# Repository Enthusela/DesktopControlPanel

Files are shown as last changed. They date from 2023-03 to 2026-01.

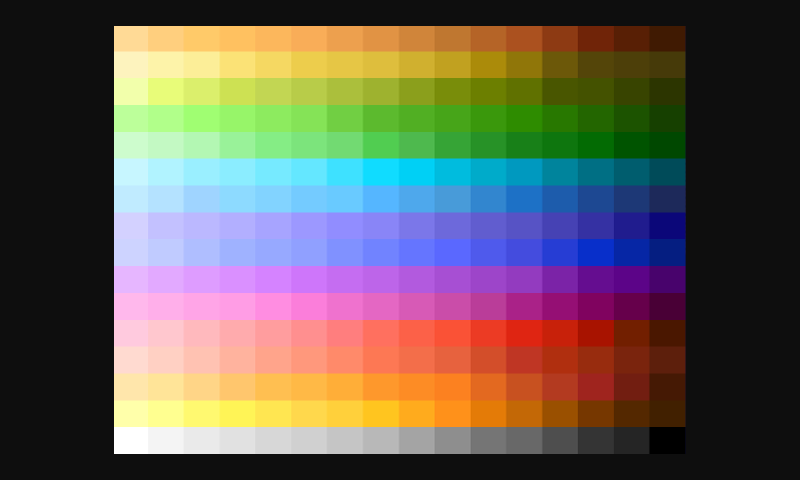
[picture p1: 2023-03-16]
eink/png/test256colors_resized.png

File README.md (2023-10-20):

# The Desktop Control Panel Project

20230719_201732_moneyShot

An open-source, hand-built, tactile, home-brew smart-home hub with analog PC audio monitoring and control.

## Features

* ARGB LED device control with HSV and color-temperature control modes
* App-based volume mixing in Windows, including OS/Game/Discord channels
* Motorised knobs enable multiple control modes on a single set of inputs
* Mains power control: Toggle switches control mains power to the PC, monitors, and speakers via rental-safe RF-based remote-control mains outlets.
* Analog audio monitoring: PC soundcard connects to VU meters and IN-9 Nixie Tubes for level and 3-band spectrum monitoring, respectively
* Moog-inspired build quality: wood cabinet, black brushed-aluminium faceplate, big, satisfying switchgear, and actual Moog knobs/rockers because why not.
* "Seamless" E-ink display: White-on-black E-ink panel creates a non-light-emitting display integrated into the non-light-emitting faceplate.
* Integrated website: the website for this Control Panel project is hosted on the Raspberry Pi running inside the Control Panel
* Integration with Home Assistant for ARGB room-lighting via ESP Wifi boards
* Automatic Temperature-based color control: automatically transition room lighting from cool to warm as the sun sets here in Perth, Western Australia.
* Homebrew phone-control app: Home Assistant has this, of course, but this sounded like a good excuse to learn React Native.

<details>
<summary>Feature Development Status Table</summary>

| Feature/Pipeline | Order In Pipeline | Sub-function | Status |
|:---|:---:|:---|:-----|
| Faceplate -> Mega Hardware Pipeline | 1 | Faceplate Input Hardware | Done |
| Faceplate -> Mega Hardware Pipeline | 2 | Faceplate Input Breakout Board | Testing |
| Faceplate -> Mega Hardware Pipeline | 3 | Mega* Input Shield | Testing |
| Mega -> Raspi Hardware Pipeline | 1 | USB Connection | Done |
| Raspi -> Uno Hardware Pipeline | 1 | USB Connection | Done |
| Raspi -> PC Hardware Pipeline | 1 | Local Wifi Connection | Done |
| Input Knob Motorisation | 1 | Mega Programming - Input Knob Control Modes | Done |
| Input Knob Motorisation | 2 | Motor Driver Shield | Done |
| Input Knob Motorisation | 3 | Shield -> Motor Connection | Done | 
| PC ARGB Control | 1 | Mega Programming - Input signal processing | Done |
| PC ARGB Control | 2a  | Raspi* Programming - Input passthrough to Uno | Done |
| PC ARGB Control | 2b  | Raspi Programming - Home Assistant/Web App | Not Started |
| PC ARGB Control | 3a  | Uno* Programming - Manual HSV-based Color Control | Done |
| PC ARGB Control | 3b  | Uno Programming - Manual Temp-based Color Control | Done |
| PC ARGB Control | 3c  | Uno Programming - Auto Temp-based Color Control | Not Started |
| PC ARGB Control | 4 | Uno ARGB Breakout Shield | To Be Ordered |
| PC ARGB Control | 5 | PC ARGB Devices | Done |
| PC Volume Control | 1 | Raspi Programming - Input passthrough to PC | Done |
| PC Volume Control | 2a  | PC Programming - Main Volume Control | Done |
| PC Volume Control | 2b  | PC Programming - Three-channel App Volume Control | Done |
| PC Volume Control | 2c  | PC Programming - Audio Output Device Selection | Done |
| Mains Power Control | 1 | Mega Programming - Input Signal Processing | In progress |
| Mains Power Control | 2 | Mega -> RF PCB Breakout Board | In progress |
| Mains Power Control | 3 | RF PCB -> Remote Mains Outlet Connection | In progress |
| Mains Power Control | 4 | Remote Mains Outlets - Test Working | In progress |
| PC Audio Level Meters | 1 | Soundcard TRS Output Levels | Done |
| PC Audio Level Meters | 2a  | Soundcard -> Driver Board Connection | Done |
| PC Audio Level Meters | 2b  | Power Supply -> Driver Board Connection | Developing |
| PC Audio Level Meters | 3 | VU Meter Driver Board | Done |
| PC Audio Level Meters | 4a  | VU Meter Level Outputs | Done |
| PC Audio Level Meters | 4b  | VU Meter LED Outputs | Done |
| PC Audio Level Meters | 5a  | VU Meters | Done |
| PC Audio Level Meters | 5b  | VU Meter LEDs | Prototyped |
| PC Audio Spectrum Analyser | 1 | Soundcard Optical Output Levels | Done |
| PC Audio Spectrum Analyser | 2 | Soundcard -> Digital I/O Board Connection | Done |
| PC Audio Spectrum Analyser | 3 | Raspberry Pi Digital Audio I/O Board | Testing |
| PC Audio Spectrum Analyser | 4 | Raspberry Pi Digital Audio I/O Processing | Developing |
| PC Audio Spectrum Analyser | 5 | Custom Nixie Tube Driver HAT | Developing |
| PC Audio Spectrum Analyser | 6 | Driver HAT -> Nixie Tube Connection | Done |
| PC Audio Spectrum Analyser | 7 | Power Supply to Driver Board | Developing |
| e-Ink Display | 1 | Raspberry Pi Programming - Image Output | Developing |
| e-Ink Display | 2 | Raspberry Pi HAT | Done |
| e-Ink Display | 3 | e-Ink Display | Done |
| Project Website | 1 | Proxy Server (nginx) | Done |
| Project Website | 2 | Domain Hosting | Done |
| Project Website | 3 | Server (node.js) | Done |
| Project Website | 4a  | Homepage | In progress |
| Project Website | 4b  | Brief | In progress |
| Project Website | 4c  | Timeline | In progress |
| Project Website | 4d  | Parts List | In progress |
| Project Website | 4e  | Gallery | In progress |
| Project Website | 4f  | Interactive Panel Map | Not started |
| Cabinet | N/A | Faceplate VU Meter Mounts | Done |
| Cabinet | N/A | Faceplate Nixie Tube Mounts | Done |
| Cabinet | N/A | Faceplate Soundcard Mount | Done |
| Cabinet | N/A | Faceplate e-Ink Display Mount | Done |
| Cabinet | N/A | Faceplate Input Knobs | Done |
| Cabinet | N/A | Faceplate Input Knob Motors/Gears | Done |
| Cabinet | N/A | Faceplate Input Rocker Switches | Done |
| Cabinet | N/A | Faceplate Input Toggle Switches | Done |
| Cabinet | N/A | Faceplate Input Push-button Switches | Done |
| Cabinet | N/A | Internal Mounting Plate | Done |
| Cabinet | N/A | Rear Plate Plate | Done |
| Cabinet | N/A | Cabinet Top Plate | Done |
| Cabinet | N/A | Cabinet Side Plates | Done |
| Cabinet | N/A | Cabinet Bottom Plate | In progress |
| Room ARGB Control | 1a  | Raspi Programming - Home Assistant Server | Not started |
| Room ARGB Control | 1b  | Raspi Programming - Home Assistant Phone App | Not started |
| Room ARGB Control | 2 | ESP32 Programming - Home Assistant Client | Not started |
| Room ARGB Control | 3 | ESP32 ARGB Breakout Shield | Prototyped  |
| Room ARGB Control | 4 | Room ARGB Devices - Confirm Working | Not started |
| e-Ink Touch Overlay | 1 | Touch Overlay | Not started |
| e-Ink Touch Overlay | 2 | Touch Overlay -> Raspi Connection | Not started |

* "Mega", "Raspi", and "Uno" refer to the Arduino Mega, Raspberry Pi, and Arduino Uno boards used, respectively.

</details>

## Background

This project grew out of a number of frustrations I was having building a killer PC setup that was both functional and aesthetically-pleasing: both important in a 1-by-1 apartment where said PC setup takes up a good third of the available living-room space.

<details>
<summary>ARGB controller software is not pleasant to use</summary>
<br>
The main idea for this project came out of my own frustration with existing hardware/software for controlling ARGB LEDs built into PC components. Most ARGB devices, like fans, must be plugged into a controller that interfaces with software running on the PC. This software is manufacturer-specific, closed-source, and typically quite limited in what it can do: you get some pre-loaded color patterns, but if you want it to do anything else, you're out of luck. To make matters worse, the software is often classic "bloatware": it insists on starting on login, then runs slow, chews up computer resources on functions you didn't ask for, and crashes often. Factor in multiple apps running for different manufacturers, and the user experience gets frustrating fast. While there is some scope to synchronise lighting across different manufacturer's products, these aren't ideal either: I was able to sync my CoolerMaster fans and my Corsair mouse, for instance, but only by using ARGB software tied to my motherboard, which was more limited than the software that came with either product.
</details> 

<details>
<summary>ARGB controller hardware is not special</summary>
<br>
Despite these software problems, I noticed that the physical connections across all my devices was using the same three-pin standard. A quick internet search taught me that the standard was, as expected, a simple Vcc-Data-Gnd pin layout.
</details>

<details>
<summary>Humans did not evolve to relax under rainbow lighting</summary>
<br>
While thinking about making my own ARGB controller, one feature that I particularly wanted was temperature-based color control. I liked the idea of room lighting that could change from cool white during the day to very warm, basically orange, at night. Ideally I'd have my whole apartment lit up like this to make it a well-lit space during the day that gradually becomes softer, warmer, and hopefully more sleep-conducive at night. This is pretty much the antithesis of most pre-built ARGB options, whether that's PC components or ARGB strip-lighting with controllers, which default to "rainbow vomit cyclone". Of course, if I had my own controller then I could make my color-temperature dreams come true.
</details>

<details>
<summary>I like my hardware ~ t e x t u r a l ~</summary>
<br>
I don't know about you, but I really love old-school electronics hardware, particularly audio hardware like synthesisers, amps, mixing tables, etc. The use of materials like wood and metal and glass makes them look and feel so much nicer, so much more hand-crafted, than anything you can get out of molded plastic. All that physical switchgear gives it a sense of weight and purpose; you just know there's a heap of clever analog wizardry going on in there as you move physical components about. It's kind of the opposite of the experience I was getting with the ARGB controllers, which is basically "plug in this small plastic box and hope the software will work". If I was ever going to build my own electronics hardware, something really cool, it would take a lot of design queues from that kind of old-school equipment.
</details>

<details>
<summary>I wanted a new job</summary>
<br>
This project became part of my Master Plan to pivot from Mechatronics Engineer to Software Engineer. If everything so far sounds like something I could have just bought one or more smart-home products to do, then yes, you're right, but as the feature set grew I realised varied tech stack required to build it would make it an ideal showcase project.
</details>

<details>
<summary>The Idea</summary>
<br>
So I have lighting software that doesn't work, connected to hardware that isn't complicated, pushing out colors I don't like, in a form factor that's the opposite of what I like in technology. What if I made the opposite of that? An open-source controller, accepting whatever standard plug-ins my devices used, with all of the color-control options I could think up, built into a sleek bit of hardware that makes you go "Nice." Maybe it'd look a little like this...
<br>
20220818_153445_ControlPanelDiagram

This repo contains (almost) everything I've built so far to make bring that digital finger-painting to life.
</details>

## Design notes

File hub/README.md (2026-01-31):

# Desktop Control Hub

Central coordination web application for the Desktop Control Panel system. This hub manages communication between various devices (Arduino, ESP32, Raspberry Pi) and provides a unified web interface for control and monitoring.

## Architecture

```
Browser (Web UI)
    ↕ Socket.IO
Hub (Node.js Server)
    ↕ Serial/GPIO/Network
Devices (Arduino, ESP32, etc.)
```

## Features

- **Real-time Communication**: Socket.IO for bidirectional updates
- **Device Coordination**: Manages multiple external devices
- **ARGB Control**: Controls addressable RGB LEDs via Arduino
- **GPIO Support**: Raspberry Pi GPIO integration (with mock mode for development)
- **Containerized**: Docker support for easy deployment

## Quick Start

### Development (Local Machine)

```bash
cd hub

# Start with Docker Compose
docker-compose up

# Or run directly with Node.js
npm install
node webserver.js
```

Access the web interface at: http://localhost:8080

### Production (Raspberry Pi)

```bash
cd hub

# Copy and configure environment
cp .env.example .env
# Edit .env with your settings

# Start production container
docker-compose -f docker-compose.prod.yml up -d
```

## Configuration

Environment variables (`.env`):

- `SERIAL_PORT`: Arduino serial port (default: `/dev/ttyACM0`)
- `GPIO_MODE`: `hardware` for Raspberry Pi, `mock` for development (default: `mock`)
- `NODE_ENV`: `development` or `production` (default: `development`)

## Device Integration

### Arduino (ARGB Control)

- **Protocol**: Serial @ 9600 baud
- **Format**: `_` + HSV bytes (Hue, Saturation, Value)
- **Device**: `/dev/ttyACM0`

### Raspberry Pi GPIO

- **LED**: GPIO 21 (output)
- **Button**: GPIO 26 (input)

## Development

### File Structure

```
hub/
├── public/              # Static web files
│   ├── index.html      # Web UI
│   └── index.js        # Client-side JavaScript
├── webserver.js        # Node.js server
├── package.json        # Dependencies
├── Dockerfile          # Container definition
└── docker-compose.yml  # Development orchestration
```

### Running without Docker

```bash
npm install
node webserver.js
```

### Hot Reload

The development Docker container uses nodemon for automatic restarts when code changes.

## API Events (Socket.IO)

### Client → Server

- `onOff` - Toggle power (0/1)
- `hsv_hue` - Set hue (0-255)
- `hsv_saturation` - Set saturation (0-255)
- `hsv_brightness` - Set brightness (0-255)

### Server → Client

- `onOff` - Power state update
- `connect` - Connection established
- `disconnect` - Connection lost

## Troubleshooting

### Arduino not detected

```bash
# List available serial ports
arduino-cli board list

# Update SERIAL_PORT in .env
```

### Permission denied on serial port

```bash
# Add user to dialout group
sudo usermod -a -G dialout $USER
# Log out and back in
```

### GPIO not working

- Ensure `GPIO_MODE=hardware` on Raspberry Pi
- Check GPIO pins are not in use by other processes
- Verify user has GPIO permissions

## Related Components

- **argb_ctrl/ard_uno/**: Arduino firmware for ARGB control
- **argb_ctrl/raspi/**: Raspberry Pi integration scripts
- **argb_ctrl/esp_wifi/**: ESP32 WiFi controller

## Future Plans

- Multi-device dashboard
- E-ink display integration
- Cabinet lighting control
- Temperature monitoring
- System status display

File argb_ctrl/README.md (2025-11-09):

# ARGB Controller - Containerized Setup

A containerized RGB LED controller that runs on both development machines and Raspberry Pi, communicating with Arduino via USB serial.

## Architecture

- **Web Interface**: Node.js server with Socket.IO for real-time control
- **Arduino Communication**: Serial connection via USB (default: `/dev/ttyACM0`)
- **GPIO Control**: Physical button support on Raspberry Pi (gracefully disabled on other systems)
- **Container**: Docker-based deployment for portability

## Prerequisites

### Development Machine
- Docker and Docker Compose installed
- Arduino connected via USB
- Linux host (for USB device passthrough)

### Raspberry Pi
- Docker and Docker Compose installed
- Arduino connected via USB
- GPIO pins 21 (LED) and 26 (button) wired (optional)

## Quick Start

### Development Mode (Your Local Machine)

1. **Find your Arduino device path:**
   ```bash
   ls -l /dev/ttyACM* /dev/ttyUSB*
   ```

2. **Update device path if needed:**
   Edit `docker-compose.yml` and update the device path:
   ```yaml
   devices:
     - /dev/ttyACM0:/dev/ttyACM0  # Change if your Arduino is on a different port
   ```

3. **Start the container:**
   ```bash
   cd argb_ctrl
   docker compose up --build
   ```

4. **Access the web interface:**
   Open your browser to `http://localhost:8080`

### Production Mode (Raspberry Pi)

1. **Build and start:**
   ```bash
   cd argb_ctrl
   docker compose -f docker-compose.prod.yml up --build -d
   ```

2. **Access the web interface:**
   From any device on the network: `http://<raspberry-pi-ip>:8080`

## Configuration

### Environment Variables

You can customize behavior in two ways:

**Option 1: Using a .env file (recommended)**
```bash
# Copy the example file and edit it
cp .env.example .env
# Edit .env with your preferred settings
```

**Option 2: Direct environment variables**
```bash
# Set before running docker compose
export SERIAL_PORT=/dev/ttyUSB0
export GPIO_MODE=mock
docker compose up
```

Available variables:
- `GPIO_MODE`: 'mock' (disable GPIO) or 'hardware' (enable GPIO)
- `SERIAL_PORT`: Arduino serial port path (default: /dev/ttyACM0)
- `NODE_ENV`: 'development' or 'production'

### USB Device Permissions

If you encounter permission errors accessing the Arduino:

```bash
# Add your user to the dialout group
sudo usermod -aG dialout $USER

# Or set device permissions (temporary, resets on reboot)
sudo chmod 666 /dev/ttyACM0
```

## Development Features

### Hot Reload
In development mode, the container uses `nodemon` to automatically restart when you edit:
- `webserver.js`
- `public/index.html`
- `public/index.js`

Changes are reflected immediately without rebuilding the container.

### Logs
```bash
# View logs
docker compose logs -f

# View only errors
docker compose logs -f | grep -i error
```

## Troubleshooting

### Arduino Not Found
```
Error: Error: Error Resource temporarily unavailable Cannot lock port
```
**Solution**:
- Check the device path: `ls -l /dev/ttyACM*`
- Update `docker-compose.yml` with correct device path
- Ensure the device isn't already open by another program
- Check permissions (see USB Device Permissions above)

### GPIO Errors on Non-Raspberry Pi
This is normal. The application will log:
```
GPIO not available: ...
Running in mock GPIO mode - physical button will not work
```
This is expected behavior on development machines. The web interface will still work.

### Port 8080 Already in Use
```bash
# Find and kill the process using port 8080
sudo lsof -i :8080
sudo kill -9 <PID>
```

### Container Won't Start
```bash
# Clean rebuild
docker compose down
docker compose up --build
```

## Project Structure

```
argb_ctrl/
├── docker-compose.yml          # Development configuration
├── docker-compose.prod.yml     # Production configuration (Raspberry Pi)
├── web_app/
│   ├── Dockerfile              # Container definition
│   ├── .dockerignore          # Files to exclude from container
│   ├── package.json           # Node.js dependencies
│   ├── webserver.js           # Main server application
│   └── public/
│       ├── index.html         # Web interface
│       └── index.js           # Client-side JavaScript
├── raspi/
│   └── ard.py                 # Python control script (alternative)
└── ard_uno/
    └── ARGBController.ino     # Arduino sketch
```

## Arduino Setup

1. Flash the Arduino with `ard_uno/ARGBController.ino`
2. Connect the Arduino via USB
3. The Arduino should appear as `/dev/ttyACM0` (or similar)
4. The web server will communicate using the protocol:
   - Send: `_` + 3 bytes (H, S, V values 0-255)
   - When off: `_` + 0, 0, 0

## Stopping the Application

### Development
```bash
docker compose down
```

### Production
```bash
docker compose -f docker-compose.prod.yml down
```

## Building for Different Platforms

### ARM64 (Raspberry Pi 4)
```bash
docker buildx build --platform linux/arm64 -t argb-web-app ./web_app
```

### AMD64 (Standard PC)
```bash
docker buildx build --platform linux/amd64 -t argb-web-app ./web_app
```

## Next Steps

1. Test the setup on your development machine
2. Customize the Arduino sketch for your RGB LED setup
3. Deploy to Raspberry Pi when ready
4. Configure autostart on Raspberry Pi boot (optional):
   ```bash
   # Add to /etc/rc.local (before 'exit 0')
   cd /path/to/argb_ctrl && docker compose -f docker-compose.prod.yml up -d
   ```

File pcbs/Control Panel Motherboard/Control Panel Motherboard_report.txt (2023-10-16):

PCB statistics report
=====================
- Date: 19/09/2023 2:00:27 PM
- Project: Control Panel Motherboard
- Board name: Control Panel Motherboard

Board
-----
- Width: 91.3384 mm
- Height: 74.6760 mm
- Area: 6820.7864 mm²

Pads
----
- Through hole: 159
- SMD: 0
- Connector: 0
- NPTH: 0

Vias
----
- Through vias: 0
- Blind/buried: 0
- Micro vias: 0

Components
----------

| | Front Side | Back Side | Total |
|---|---|---|---|
|THT: | 43 | 0 | 43 |
|SMD: | 0 | 0 | 0 |
|Unspecified:  | 0 | 0 | 0 |
|Total: | 43 | 0 | 43 |

Drill holes
-----------

| Count | Shape | X Size | Y Size | Plated | Via/Pad | Start Layer | Stop Layer |
|---|---|---|---|---|---|---|---|
| 59 | Round | 1.5200 mm | 1.5200 mm | PTH | Pad | F.Cu | B.Cu |
| 36 | Round | 0.8000 mm | 0.8000 mm | PTH | Pad | F.Cu | B.Cu |
| 30 | Round | 1.0000 mm | 1.0000 mm | PTH | Pad | F.Cu | B.Cu |
| 18 | Round | 0.7000 mm | 0.7000 mm | PTH | Pad | F.Cu | B.Cu |
| 16 | Round | 0.9000 mm | 0.9000 mm | PTH | Pad | F.Cu | B.Cu |

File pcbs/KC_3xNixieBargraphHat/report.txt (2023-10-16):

Info: Backing up file 'C:\Users\natha\OneDrive\Documents\Projects\Control Panel\Custom PCBs\KC_3xNixieBargraphHat\sym-lib-table' to 'C:\Users\natha\OneDrive\Documents\Projects\Control Panel\Custom PCBs\KC_3xNixieBargraphHat\rescue-backup\sym-lib-table-2023-09-20-15-47-16'.
Info: Backing up file 'C:\Users\natha\OneDrive\Documents\Projects\Control Panel\Custom PCBs\KC_3xNixieBargraphHat\KC_3xNixieBargraphHat.sch' to 'C:\Users\natha\OneDrive\Documents\Projects\Control Panel\Custom PCBs\KC_3xNixieBargraphHat\rescue-backup\KC_3xNixieBargraphHat-2023-09-20-15-47-16.sch'.
Info: Backing up file 'C:\Users\natha\OneDrive\Documents\Projects\Control Panel\Custom PCBs\KC_3xNixieBargraphHat\KC_3xNixieBargraphHat.kicad_pro' to 'C:\Users\natha\OneDrive\Documents\Projects\Control Panel\Custom PCBs\KC_3xNixieBargraphHat\rescue-backup\KC_3xNixieBargraphHat-2023-09-20-15-47-16.kicad_pro'.
Info: Backing up file 'C:\Users\natha\OneDrive\Documents\Projects\Control Panel\Custom PCBs\KC_3xNixieBargraphHat\KC_3xNixieBargraphHat-cache.lib' to 'C:\Users\natha\OneDrive\Documents\Projects\Control Panel\Custom PCBs\KC_3xNixieBargraphHat\rescue-backup\KC_3xNixieBargraphHat-cache-2023-09-20-15-47-16.lib'.
Info: Backing up file 'C:\Users\natha\OneDrive\Documents\Projects\Control Panel\Custom PCBs\KC_3xNixieBargraphHat\KC_3xNixieBargraphHat-rescue.lib' to 'C:\Users\natha\OneDrive\Documents\Projects\Control Panel\Custom PCBs\KC_3xNixieBargraphHat\rescue-backup\KC_3xNixieBargraphHat-rescue-2023-09-20-15-47-16.lib'.
Info: Backing up file 'C:\Users\natha\OneDrive\Documents\Projects\Control Panel\Custom PCBs\KC_3xNixieBargraphHat\KC_3xNixieBargraphHat-rescue.dcm' to 'C:\Users\natha\OneDrive\Documents\Projects\Control Panel\Custom PCBs\KC_3xNixieBargraphHat\rescue-backup\KC_3xNixieBargraphHat-rescue-2023-09-20-15-47-16.dcm'.
Info: Adding library 'KC_3xNixieBargraphHat-rescue', file '${KIPRJMOD}/KC_3xNixieBargraphHat-rescue.lib' to project symbol library table.
Symbol R mapped to symbol library 'KC_3xNixieBargraphHat-rescue'.
Symbol GND mapped to symbol library 'KC_3xNixieBargraphHat-rescue'.
Symbol +170V mapped to symbol library 'KC_3xNixieBargraphHat-rescue'.
Symbol Screw_Terminal_1x02 mapped to symbol library 'KC_3xNixieBargraphHat-rescue'.
Symbol GND mapped to symbol library 'KC_3xNixieBargraphHat-rescue'.
Symbol Screw_Terminal_1x03 mapped to symbol library 'KC_3xNixieBargraphHat-rescue'.
Symbol R mapped to symbol library 'KC_3xNixieBargraphHat-rescue'.
Symbol +170V mapped to symbol library 'KC_3xNixieBargraphHat-rescue'.
Symbol Screw_Terminal_1x03 mapped to symbol library 'KC_3xNixieBargraphHat-rescue'.
Symbol +5V mapped to symbol library 'KC_3xNixieBargraphHat-rescue'.
Symbol IN-9 mapped to symbol library 'KC_3xNixieBargraphHat-rescue'.
Symbol +170V mapped to symbol library 'KC_3xNixieBargraphHat-rescue'.
Symbol BSP129 mapped to symbol library 'KC_3xNixieBargraphHat-rescue'.
Symbol Screw_Terminal_1x03 mapped to symbol library 'KC_3xNixieBargraphHat-rescue'.
Symbol R mapped to symbol library 'KC_3xNixieBargraphHat-rescue'.
Symbol GND mapped to symbol library 'KC_3xNixieBargraphHat-rescue'.
Symbol R mapped to symbol library 'KC_3xNixieBargraphHat-rescue'.
Symbol GND mapped to symbol library 'KC_3xNixieBargraphHat-rescue'.
Symbol R mapped to symbol library 'KC_3xNixieBargraphHat-rescue'.
Symbol +3.3V mapped to symbol library 'KC_3xNixieBargraphHat-rescue'.
Symbol GND mapped to symbol library 'KC_3xNixieBargraphHat-rescue'.
Symbol Raspberry_PI_Zero_Hat mapped to symbol library 'KC_3xNixieBargraphHat-rescue'.
Symbol R mapped to symbol library 'KC_3xNixieBargraphHat-rescue'.
Symbol GND mapped to symbol library 'KC_3xNixieBargraphHat-rescue'.
Symbol GND mapped to symbol library 'KC_3xNixieBargraphHat-rescue'.
Symbol R mapped to symbol library 'KC_3xNixieBargraphHat-rescue'.
Symbol R mapped to symbol library 'KC_3xNixieBargraphHat-rescue'.
Symbol R mapped to symbol library 'KC_3xNixieBargraphHat-rescue'.
Symbol R mapped to symbol library 'KC_3xNixieBargraphHat-rescue'.
Symbol +5V mapped to symbol library 'KC_3xNixieBargraphHat-rescue'.
Symbol R mapped to symbol library 'KC_3xNixieBargraphHat-rescue'.
Symbol R mapped to symbol library 'KC_3xNixieBargraphHat-rescue'.
Symbol R mapped to symbol library 'KC_3xNixieBargraphHat-rescue'.
Symbol R mapped to symbol library 'KC_3xNixieBargraphHat-rescue'.
Symbol R mapped to symbol library 'KC_3xNixieBargraphHat-rescue'.
Symbol BSP129 mapped to symbol library 'KC_3xNixieBargraphHat-rescue'.
Symbol IN-9 mapped to symbol library 'KC_3xNixieBargraphHat-rescue'.
Symbol MCP6001 mapped to symbol library 'KC_3xNixieBargraphHat-rescue'.
Symbol C mapped to symbol library 'KC_3xNixieBargraphHat-rescue'.
Symbol 2N7002 mapped to symbol library 'KC_3xNixieBargraphHat-rescue'.
Symbol GND mapped to symbol library 'KC_3xNixieBargraphHat-rescue'.
Symbol R mapped to symbol library 'KC_3xNixieBargraphHat-rescue'.
Symbol R mapped to symbol library 'KC_3xNixieBargraphHat-rescue'.
Symbol R mapped to symbol library 'KC_3xNixieBargraphHat-rescue'.
Symbol C mapped to symbol library 'KC_3xNixieBargraphHat-rescue'.
Symbol GND mapped to symbol library 'KC_3xNixieBargraphHat-rescue'.
Symbol C mapped to symbol library 'KC_3xNixieBargraphHat-rescue'.
Symbol GND mapped to symbol library 'KC_3xNixieBargraphHat-rescue'.
Symbol C mapped to symbol library 'KC_3xNixieBargraphHat-rescue'.
Symbol GND mapped to symbol library 'KC_3xNixieBargraphHat-rescue'.
Symbol GND mapped to symbol library 'KC_3xNixieBargraphHat-rescue'.
Symbol GND mapped to symbol library 'KC_3xNixieBargraphHat-rescue'.
Symbol R mapped to symbol library 'KC_3xNixieBargraphHat-rescue'.
Symbol GND mapped to symbol library 'KC_3xNixieBargraphHat-rescue'.
Symbol D_x2_Serial_AKC mapped to symbol library 'KC_3xNixieBargraphHat-rescue'.
Symbol D_x2_Serial_AKC mapped to symbol library 'KC_3xNixieBargraphHat-rescue'.
Symbol +3.3V mapped to symbol library 'KC_3xNixieBargraphHat-rescue'.
Symbol C mapped to symbol library 'KC_3xNixieBargraphHat-rescue'.
Symbol +5V mapped to symbol library 'KC_3xNixieBargraphHat-rescue'.
Symbol +3.3V mapped to symbol library 'KC_3xNixieBargraphHat-rescue'.
Symbol R mapped to symbol library 'KC_3xNixieBargraphHat-rescue'.
Symbol D_x2_Serial_AKC mapped to symbol library 'KC_3xNixieBargraphHat-rescue'.
Symbol C mapped to symbol library 'KC_3xNixieBargraphHat-rescue'.
Symbol GND mapped to symbol library 'KC_3xNixieBargraphHat-rescue'.
Symbol GND mapped to symbol library 'KC_3xNixieBargraphHat-rescue'.
Symbol GND mapped to symbol library 'KC_3xNixieBargraphHat-rescue'.
Symbol D_x2_Serial_AKC mapped to symbol library 'KC_3xNixieBargraphHat-rescue'.
Symbol R mapped to symbol library 'KC_3xNixieBargraphHat-rescue'.
Symbol R mapped to symbol library 'KC_3xNixieBargraphHat-rescue'.
Symbol 2N7002 mapped to symbol library 'KC_3xNixieBargraphHat-rescue'.
Symbol GND mapped to symbol library 'KC_3xNixieBargraphHat-rescue'.
Symbol C mapped to symbol library 'KC_3xNixieBargraphHat-rescue'.
Symbol R mapped to symbol library 'KC_3xNixieBargraphHat-rescue'.
Symbol R mapped to symbol library 'KC_3xNixieBargraphHat-rescue'.
Symbol GND mapped to symbol library 'KC_3xNixieBargraphHat-rescue'.
Symbol +5V mapped to symbol library 'KC_3xNixieBargraphHat-rescue'.
Symbol C mapped to symbol library 'KC_3xNixieBargraphHat-rescue'.
Symbol GND mapped to symbol library 'KC_3xNixieBargraphHat-rescue'.
Symbol MCP6001 mapped to symbol library 'KC_3xNixieBargraphHat-rescue'.
Symbol C mapped to symbol library 'KC_3xNixieBargraphHat-rescue'.
Symbol GND mapped to symbol library 'KC_3xNixieBargraphHat-rescue'.
Info: Symbol library table mapping complete!
Info: Created project symbol library table.

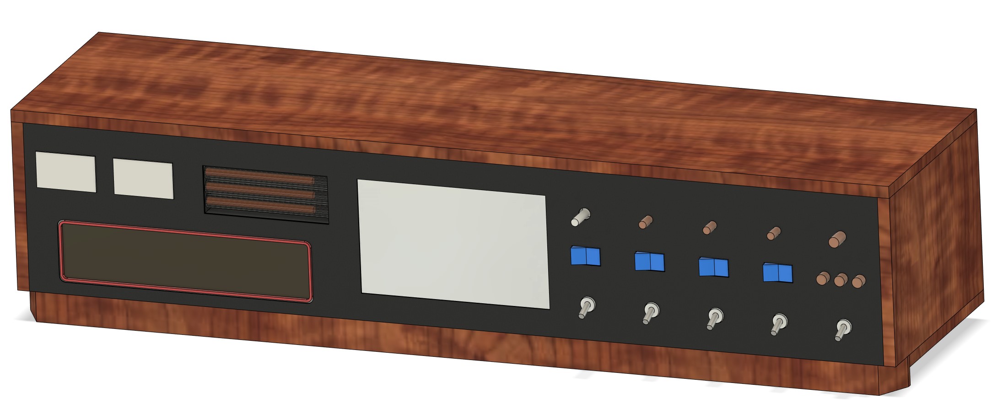
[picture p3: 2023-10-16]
cabinet/imgs/Control Panel Mock-up - Face Plate.jpg

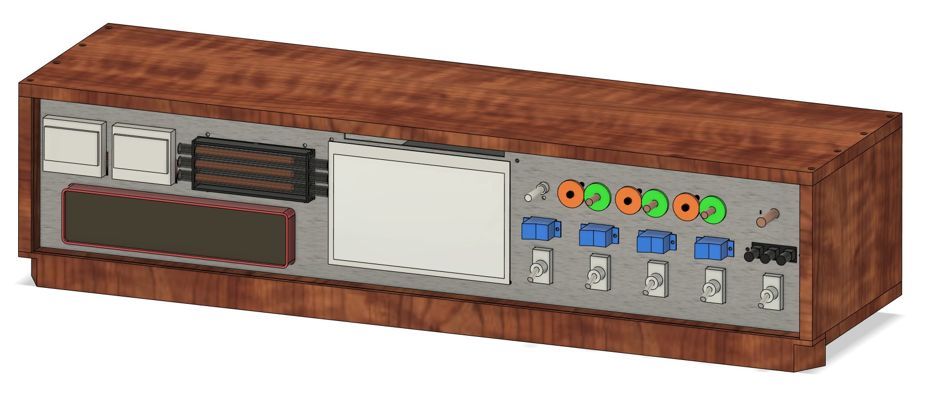
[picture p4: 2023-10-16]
cabinet/imgs/Control Panel Mock-up - Mounting Plate.jpg

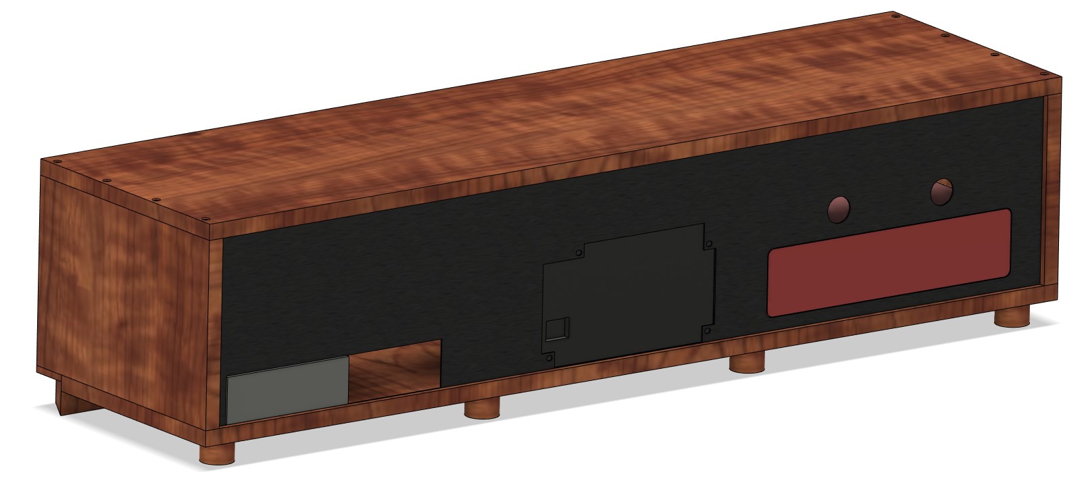
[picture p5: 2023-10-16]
cabinet/imgs/Control Panel Mock-up - Rear Plate.jpg

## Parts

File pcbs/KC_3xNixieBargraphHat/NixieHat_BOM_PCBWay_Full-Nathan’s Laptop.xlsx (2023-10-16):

 |  |  | xxxx xxxx xxxxx xxPCS BOM
 |  |  |  |  |  | 30
Item # | *Designator | *Qty | Manufacturer | *Mfg Part # | Description / Value | *Package/Footprint | Type | Your Instructions / Notes
1 | C1, C5, C10 | 3 | Kemet | C0805C332J4HACTU | 3.3nF | Capacitor_SMD:C_0805_2012Metric_Pad1.18x1.45mm_HandSolder | SMD | Found at: https://www.xonelec.com/mpn/kemet/c0805c332j4hactu
2 | C2, C6, C11 | 3 | Kemet | C0805C104J8RACTU | 0.1uF | Capacitor_SMD:C_0805_2012Metric_Pad1.18x1.45mm_HandSolder | SMD | Found at: https://www.xonelec.com/mpn/kemet/c0805c104j8ractu
3 | C3, C4, C7, C13 | 4 | Kemet | C0805C105J4RACTU | 1uF | Capacitor_SMD:C_0805_2012Metric_Pad1.18x1.45mm_HandSolder | SMD | Found at: https://www.xonelec.com/mpn/kemet/c0805c105j4ractu
4 | C8, C9, C12 | 3 | Kemet | C0805C102J4GACTU | 1nF | Capacitor_SMD:C_0805_2012Metric_Pad1.18x1.45mm_HandSolder | SMD | Found at: https://www.xonelec.com/mpn/kemet/c0805c102j4gactu
5 | D1-D6 | 6 | Nexperia USA Inc. | BAV99,215 | BAV99 | Package_TO_SOT_SMD:SOT-23 | SMD | Found at: https://www.pcbway.com/components/detail/BAV99215/340224/
6 | J1-J3 | 3 | Molex | 0397730002 | Screw_Terminal_1x02 | TerminalBlock_Phoenix:TerminalBlock_Phoenix_MPT-0,5-2-2.54_1x02_P2.54mm_Horizontal | PTH | Found at: https://www.pcbway.com/components/detail/0397730002/883047/
7 | Q1, Q3, Q5 | 3 | ON Semiconductor | FDD7N25LZTM | FDD7N25LZTM | Package_TO_SOT_SMD:TO-252-2 | SMD | Found at: https://www.xonelec.com/mpn/onsemiconductor/fdd7n25lztm
8 | Q2, Q4, Q6 | 3 | Micro Commercial Components (MCC) | 2N7002-TP | 2N7002 | Package_TO_SOT_SMD:SOT-23 | SMD | Found at: https://www.xonelec.com/mpn/microcommercialcomponentsmcc/2n7002tp
9 | R1, R2, R5-R10, R20, R25-R28 | 13 | Yageo | RT0805FRE071KL | 1k | Resistor_SMD:R_0805_2012Metric_Pad1.20x1.40mm_HandSolder | SMD
10 | R3, R11, R29 | 3 | Vishay | PR02000201001FR500 | 1k 2W | Resistor_THT:R_Axial_DIN0411_L9.9mm_D3.6mm_P12.70mm_Horizontal | PTH
11 | R4, R12, R22, R30 | 3 | Yageo | RT0805FRE07130RL | 133 | Resistor_SMD:R_0805_2012Metric_Pad1.15x1.40mm_HandSolder | SMD
12 | R18 | 1 | Yageo | RT0805FRE07100KL | 100k | Resistor_SMD:R_0805_2012Metric_Pad1.20x1.40mm_HandSolder | SMD
13 | R32 | 1 | Yageo | RT0805FRE0747KL | 47k | Resistor_SMD:R_0805_2012Metric_Pad1.20x1.40mm_HandSolder | SMD
14 | U1, U3, U4 | 3 | Microchip | MCP6411T-E/OT | MCP6411 | Package_TO_SOT_SMD:TSOT-23-5_HandSoldering | SMD | Found at: https://www.xonelec.com/mpn/microchip/mcp6411teot
15 | U5 | 1 | Lite-on | LTV-817-A | LTV-817 | Package_DIP:DIP-4_W7.62mm | PTH
Need a quick and accurante quote? Need an efficient production? Please read SMT Ordering Necessary Files & Info in 1 minute. Thank you very much! (https://www.pcbway.com/smt_ordering_guide.html)
Click for Instructions on How to Create a BOM (https://www.pcbway.com/blog/PCB_Assembly/How_to_Build_a_BOM__Bill_Of_Materials_.html)

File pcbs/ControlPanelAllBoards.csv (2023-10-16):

Board | Qty | In Mouser Cart | In Jaycar Cart | In X-On Cart | Footprint | Reference | Value | Datasheet
Selector | 13 | N/A | N/A | N/A | Connector_Pin:Pin_D1.0mm_L10.0mm | > J1-J13 | Conn_01x01_Female | ~
Mega_Shield | 1 | N/A | N/A | N/A | PCM_arduino-library:Arduino_Mega2560_Shield | XA1 | Arduino_Mega2560_Shield | https://docs.arduino.cc/hardware/mega-2560
MegaShield | 1 | No | Yes | No | Connector_IDC:IDC-Header_2x05_P2.54mm_Vertical | J3 | IDC_RF | ~
RF_Breakout | 1 | No | Yes | No | Connector_IDC:IDC-Header_2x05_P2.54mm_Vertical | IDC_RF1 | IDC_SW | ~
MegaShield | 1 | Yes | Yes | No | Connector_IDC:IDC-Header_2x10_P2.54mm_Vertical | J1 | IDC_SW | ~
IO_Breakout | 1 | No | Yes | No | Connector_IDC:IDC-Header_2x10_P2.54mm_Vertical | J11 | J_IDC_SW_IN | ~
MegaShield | 1 | No | Yes | No | IDC Cable _2x05 _P2.54mm_Vertical | N/A
MegaShield | 1 | No | Yes | No | IDC Cable _2x10 _P2.54mm_Vertical | N/A
MegaShield | 1 | Yes |  | Yes | Button_Switch_THT:SW_DIP_SPSTx02_Slide_9.78x7.26mm_W7.62mm_P2.54mm | SW2 | SW_DIP_x02 | ~
MegaShield | 1 | Yes |  | Yes | Button_Switch_THT:SW_PUSH_6mm_H5mm | SW1 | SW_Push | ~
RF_Breakout | 4 | Yes |  | Yes | LED_THT:LED_D3.0mm | > D1, D3, D5, D7 | LED-ON | ~
RF_Breakout | 4 | Yes |  | Yes | LED_THT:LED_D3.0mm | > D2, D4, D6, D8 | LED-OFF | ~
RF_Breakout | 2 | Yes |  | Yes | Package_DIP:DIP-16_W7.62mm | > U2, U3 | LTV-847 | http://optoelectronics.liteon.com/upload/download/DS-70-96-0016/LTV-8X7%20series.PDF
IO_Breakout | 1 | Yes |  | Yes | Package_DIP:DIP-4_W7.62mm | U1 | LTV-817 | http://www.us.liteon.com/downloads/LTV-817-827-847.PDF
Selector | 12 | No |  | Yes | Resistor_THT:R_Axial_DIN0204_L3.6mm_D1.6mm_P5.08mm_Horizontal | > R1-R12 | 330R | ~
IO_Breakout | 1 | Yes |  | Yes | Resistor_THT:R_Axial_DIN0207_L6.3mm_D2.5mm_P7.62mm_Horizontal | R1 | 330R | ~
RF_Breakout | 8 | No |  | Yes | Resistor_THT:R_Axial_DIN0207_L6.3mm_D2.5mm_P7.62mm_Horizontal | > R2-R9 | 330R | ~
IO_Breakout | 3 | Yes |  | Yes | TerminalBlock:TerminalBlock_bornier-2_P5.08mm | > J9, J10, J12 | Screw_Terminal_01x02 | ~
RF_Breakout | 1 | Yes |  | Yes | TerminalBlock:TerminalBlock_bornier-2_P5.08mm | J22 | Screw_Terminal_01x02 | ~
MegaShield | 1 | Yes |  | Yes | TerminalBlock:TerminalBlock_bornier-3_P5.08mm | J2 | Screw_Terminal_01x03 | ~
Selector | 1 | Yes |  | Yes | TerminalBlock:TerminalBlock_bornier-3_P5.08mm | J14 | Screw_Terminal_01x03 | ~
IO_Breakout | 13 | Yes |  | Yes | TerminalBlock:TerminalBlock_bornier-3_P5.08mm | > J1-J8, J13-J17 | Screw_Terminal_01x03 | ~
RF_Breakout | 4 | Yes |  | Yes | TerminalBlock:TerminalBlock_bornier-3_P5.08mm | > J18-J21 | Screw_Terminal_01x03 | ~

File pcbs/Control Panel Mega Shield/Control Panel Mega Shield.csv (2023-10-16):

Reference | Value | Footprint | Datasheet | Qty
J1 | IDC_SW | Connector_IDC:IDC-Header_2x10_P2.54mm_Vertical | ~ | 1
J2 | Screw_Terminal_01x03 | TerminalBlock:TerminalBlock_bornier-3_P5.08mm | ~ | 1
J3 | IDC_RF | Connector_IDC:IDC-Header_2x05_P2.54mm_Vertical | ~ | 1
SW1 | SW_Push | Button_Switch_THT:SW_PUSH_6mm_H5mm | ~ | 1
SW2 | SW_DIP_x02 | Button_Switch_THT:SW_DIP_SPSTx02_Slide_9.78x7.26mm_W7.62mm_P2.54mm | ~ | 1
XA1 | Arduino_Mega2560_Shield | PCM_arduino-library:Arduino_Mega2560_Shield | https://docs.arduino.cc/hardware/mega-2560 | 1

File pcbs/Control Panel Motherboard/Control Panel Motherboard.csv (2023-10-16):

Reference | Value | Footprint | Datasheet | Qty
D1-D8 | LED | LED_THT:LED_D3.0mm | ~ | 8
IDC_RF1 | IDC_SW | Connector_IDC:IDC-Header_2x05_P2.54mm_Vertical | ~ | 1
J1-J8, J13-J21 | Screw_Terminal_01x03 | TerminalBlock:TerminalBlock_bornier-3_P5.08mm | ~ | 17
J9, J10, J12, J22 | Screw_Terminal_01x02 | TerminalBlock:TerminalBlock_bornier-2_P5.08mm | ~ | 4
J11 | J_IDC_SW_IN | Connector_IDC:IDC-Header_2x10_P2.54mm_Vertical | ~ | 1
R1-R9 | 330R | Resistor_THT:R_Axial_DIN0204_L3.6mm_D1.6mm_P5.08mm_Horizontal | ~ | 9
U1 | LTV-817 | Package_DIP:DIP-4_W7.62mm | http://www.us.liteon.com/downloads/LTV-817-827-847.PDF | 1
U2, U3 | LTV-847 | Package_DIP:DIP-16_W7.62mm | http://optoelectronics.liteon.com/upload/download/DS-70-96-0016/LTV-8X7%20series.PDF | 2

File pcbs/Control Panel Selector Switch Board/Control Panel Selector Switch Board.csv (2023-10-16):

Reference | Value | Footprint | Datasheet | Qty
J1-J13 | Conn_01x01_Female | Connector_Pin:Pin_D1.0mm_L10.0mm | ~ | 13
J14 | Screw_Terminal_01x03 | TerminalBlock:TerminalBlock_bornier-3_P5.08mm | ~ | 1
R1-R12 | 330R | Resistor_THT:R_Axial_DIN0207_L6.3mm_D2.5mm_P7.62mm_Horizontal | ~ | 12

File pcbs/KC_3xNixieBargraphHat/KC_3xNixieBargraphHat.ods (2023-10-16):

Source: | /home/mark/Dropbox/personal/SurfnCircuits/NixieBarGraphHat/KC_NixieBargraphHat/NixieBargraphHat.sch
Date: | Sat 06 Apr 2019 09:19:30 PM PDT
Tool: | Eeschema 4.0.7-e2-6376~61~ubuntu18.04.1
Generator: | /usr/lib/kicad/plugins/bom_csv_grouped_by_value.py
Component Count: | 50
Individual Components:
Item | Qty | Reference(s) | Value | LibPart | Footprint | Datasheet | MPN
 |  | C1 | 3.3nF | device:C | Capacitors_SMD:C_0805_HandSoldering | https://www.digikey.com/product-detail/en/kemet/C0805C332KDRACAUTO/399-16654-1-ND/8110020 | C0805C332KDRACAUTO
 |  | C2 | 0.1uF | device:C | Capacitors_SMD:C_0805_HandSoldering | https://www.digikey.com/product-detail/en/kemet/C0805C104K3RACTU/399-1168-2-ND/411167 | C0805C104K3RACTU
 |  | C3 | 1uF | device:C | Capacitors_SMD:C_0805_HandSoldering | https://www.digikey.com/product-detail/en/samsung-electro-mechanics/CL21F105ZBFNNNE/1276-3010-2-ND/3888668 | CL21F105ZBFNNNE
 |  | C4 | 1uF | device:C | Capacitors_SMD:C_0805_HandSoldering | https://www.digikey.com/product-detail/en/samsung-electro-mechanics/CL21F105ZBFNNNE/1276-3010-2-ND/3888668 | CL21F105ZBFNNNE
 |  | C5 | 3.3nF | device:C | Capacitors_SMD:C_0805_HandSoldering | https://www.digikey.com/product-detail/en/kemet/C0805C332KDRACAUTO/399-16654-1-ND/8110020 | C0805C332KDRACAUTO
 |  | C6 | 0.1uF | device:C | Capacitors_SMD:C_0805_HandSoldering | https://www.digikey.com/product-detail/en/kemet/C0805C104K3RACTU/399-1168-2-ND/411167 | C0805C104K3RACTU
 |  | C7 | 1uF | device:C | Capacitors_SMD:C_0805_HandSoldering | https://www.digikey.com/product-detail/en/samsung-electro-mechanics/CL21F105ZBFNNNE/1276-3010-2-ND/3888668 | CL21F105ZBFNNNE
 |  | C8 | 1nF | device:C | Capacitors_SMD:C_0805_HandSoldering | https://www.digikey.com/product-detail/en/kemet/C0805C102J5HACAUTO/399-16591-1-ND/7943643 | C0805C102J5HACAUTO
 |  | C9 | 1nF | device:C | Capacitors_SMD:C_0805_HandSoldering | https://www.digikey.com/product-detail/en/kemet/C0805C102J5HACAUTO/399-16591-1-ND/7943643 | C0805C102J5HACAUTO
 |  | D1 | BAV99 | device:D_x2_Serial_AKC | TO_SOT_Packages_SMD:SOT-23 | https://www.digikey.com/product-detail/en/nexperia-usa-inc/BAV99235/1727-4311-1-ND/2209921 | BAV99,235
 |  | D2 | BAV99 | device:D_x2_Serial_AKC | TO_SOT_Packages_SMD:SOT-23 | https://www.digikey.com/product-detail/en/nexperia-usa-inc/BAV99235/1727-4311-1-ND/2209921 | BAV99,235
 |  | D3 | BAV99 | device:D_x2_Serial_AKC | TO_SOT_Packages_SMD:SOT-23 | https://www.digikey.com/product-detail/en/nexperia-usa-inc/BAV99235/1727-4311-1-ND/2209921 | BAV99,235
 |  | D4 | BAV99 | device:D_x2_Serial_AKC | TO_SOT_Packages_SMD:SOT-23 | https://www.digikey.com/product-detail/en/nexperia-usa-inc/BAV99235/1727-4311-1-ND/2209921 | BAV99,235
 |  | J1 | Screw_Terminal_1x03 | NixieSupply5vto170vDCMBoostMini-cache:Screw_Terminal_1x03 | TerminalBlock_Phoenix:TerminalBlock_Phoenix_MPT-2.54mm_3pol | https://www.digikey.com/product-detail/en/phoenix-contact/1725669/277-1274-ND/267463 | 1725669
 |  | J2 | Screw_Terminal_1x02 | NixieSupply5vto170vDCMBoostMini-cache:Screw_Terminal_1x02 | TerminalBlock_Phoenix:TerminalBlock_Phoenix_MPT-2.54mm_2pol | https://www.digikey.com/product-detail/en/phoenix-contact/1725656/277-1273-ND/267462 | 1725656
 |  | J3 | Screw_Terminal_1x03 | NixieSupply5vto170vDCMBoostMini-cache:Screw_Terminal_1x03 | TerminalBlock_Phoenix:TerminalBlock_Phoenix_MPT-2.54mm_3pol | https://www.digikey.com/product-detail/en/phoenix-contact/1725669/277-1274-ND/267463 | 1725669
 |  | J4 | Screw_Terminal_1x03 | NixieSupply5vto170vDCMBoostMini-cache:Screw_Terminal_1x03 | TerminalBlock_Phoenix:TerminalBlock_Phoenix_MPT-2.54mm_3pol | https://www.digikey.com/product-detail/en/phoenix-contact/1725669/277-1274-ND/267463 | 1725669
 |  | N1 | IN-9 | nixies-us:IN-9 | nixies-us_IN-9
 |  | N2 | IN-9 | nixies-us:IN-9 | nixies-us_IN-9
 |  | Q1 | FDD7N25LZTM | transistors:BSP129 | TO_SOT_Packages_SMD:TO-252-2Lead | https://www.digikey.com/product-detail/en/on-semiconductor/FDD7N25LZTM/FDD7N25LZTMCT-ND/3908038 | FDD7N25LZTM
 |  | Q2 | 2N7002 | transistors:2N7002 | TO_SOT_Packages_SMD:SOT-23 | https://www.digikey.com/product-detail/en/micro-commercial-co/2N7002-TP/2N7002-TPMSTR-ND/1959296 | 2N7002-TP
 |  | Q3 | FDD7N25LZTM | transistors:BSP129 | TO_SOT_Packages_SMD:TO-252-2Lead | https://www.digikey.com/product-detail/en/on-semiconductor/FDD7N25LZTM/FDD7N25LZTMCT-ND/3908038 | FDD7N25LZTM
 |  | Q4 | 2N7002 | transistors:2N7002 | TO_SOT_Packages_SMD:SOT-23 | https://www.digikey.com/product-detail/en/micro-commercial-co/2N7002-TP/2N7002-TPMSTR-ND/1959296 | 2N7002-TP
 |  | R1 | 1k | device:R | Resistors_SMD:R_0805_HandSoldering | https://www.digikey.com/product-detail/en/yageo/RC0805FR-071KL/311-1.00KCRCT-ND/730391 | RC0805FR-071KL
 |  | R2 | 1k | device:R | Resistors_SMD:R_0805_HandSoldering | https://www.digikey.com/product-detail/en/yageo/RC0805FR-071KL/311-1.00KCRCT-ND/730391 | RC0805FR-078K2L
 |  | R3 | 1k 2W | device:R | Resistors_THT:R_Axial_DIN0411_L9.9mm_D3.6mm_P12.70mm_Horizontal | https://www.digikey.com/product-detail/en/vishay-bc-components/PR02000201001JR500/PPC1.0KW-2TR-ND/596130 | PR02000201001JR500
 |  | R4 | 133 | device:R | Resistors_SMD:R_0805_HandSoldering | https://www.digikey.com/product-detail/en/yageo/RC0805FR-07133RL/311-133CRCT-ND/730538 | RC0805FR-07133RL
 |  | R5 | 1k | device:R | Resistors_SMD:R_0805_HandSoldering | https://www.digikey.com/product-detail/en/yageo/RC0805FR-071KL/311-1.00KCRCT-ND/730391 | RC0805FR-071KL
 |  | R6 | 1k | device:R | Resistors_SMD:R_0805_HandSoldering | https://www.digikey.com/product-detail/en/yageo/RC0805FR-071KL/311-1.00KCRCT-ND/730391 | RC0805FR-071KL
 |  | R7 | 1k | device:R | Resistors_SMD:R_0805_HandSoldering | https://www.digikey.com/product-detail/en/yageo/RC0805FR-071KL/311-1.00KCRCT-ND/730391 | RC0805FR-071KL
 |  | R8 | 1k | device:R | Resistors_SMD:R_0805_HandSoldering | https://www.digikey.com/product-detail/en/yageo/RC0805FR-071KL/311-1.00KCRCT-ND/730391 | RC0805FR-071KL
 |  | R9 | 1k | device:R | Resistors_SMD:R_0805_HandSoldering | https://www.digikey.com/product-detail/en/yageo/RC0805FR-071KL/311-1.00KCRCT-ND/730391 | RC0805FR-078K2L
 |  | R10 | 1k | device:R | Resistors_SMD:R_0805_HandSoldering | https://www.digikey.com/product-detail/en/yageo/RC0805FR-071KL/311-1.00KCRCT-ND/730391 | RC0805FR-071KL
 |  | R11 | 1k 2W | device:R | Resistors_THT:R_Axial_DIN0411_L9.9mm_D3.6mm_P12.70mm_Horizontal | https://www.digikey.com/product-detail/en/vishay-bc-components/PR02000201001JR500/PPC1.0KW-2TR-ND/596130 | PR02000201001JR500
 |  | R12 | 133 | device:R | Resistors_SMD:R_0805_HandSoldering | https://www.digikey.com/product-detail/en/yageo/RC0805FR-07133RL/311-133CRCT-ND/730538 | RC0805FR-07133RL
 |  | R13 | 220k | device:R | Resistors_SMD:R_0805_HandSoldering | https://www.digikey.com/product-detail/en/te-connectivity-passive-product/CRGCQ0805F220K/A129777CT-ND/8577609 | CRGCQ0805F220K
 |  | R14 | 220k | device:R | Resistors_SMD:R_0805_HandSoldering | https://www.digikey.com/product-detail/en/te-connectivity-passive-product/CRGCQ0805F220K/A129777CT-ND/8577609 | CRGCQ0805F220K
 |  | R15 | NU | device:R | Resistors_SMD:R_0805_HandSoldering
 |  | R16 | 0 | device:R | Resistors_SMD:R_0805_HandSoldering
 |  | R17 | 0 | device:R | Resistors_SMD:R_0805_HandSoldering
 |  | R18 | NU | device:R | Resistors_SMD:R_0805_HandSoldering
 |  | R19 | 0 | device:R | Resistors_SMD:R_0805_HandSoldering
 |  | R20 | 1k | device:R | Resistors_SMD:R_0805_HandSoldering | https://www.digikey.com/product-detail/en/yageo/RC0805FR-071KL/311-1.00KCRCT-ND/730391
 |  | R21 | 0 | device:R | Resistors_SMD:R_0805_HandSoldering
 |  | R22 | NU | device:R | Resistors_SMD:R_0805_HandSoldering
 |  | R23 | NU | device:R | Resistors_SMD:R_0805_HandSoldering
 |  | R24 | NU | device:R | Resistors_SMD:R_0805_HandSoldering
 |  | U1 | MCP6411 | linear:MCP6001 | TO_SOT_Packages_SMD:SOT-23-5_HandSoldering | http://ww1.microchip.com/downloads/en/DeviceDoc/20005791B.pdf | MCP6411T-E/OT
 |  | U2 | Raspberry_PI_Zero_Header | ETAclock-cache:Raspberry_PI_Zero_Hat | etaclock:Raspberry_Pi_Zero_40pins
 |  | U3 | MCP6411 | linear:MCP6001 | TO_SOT_Packages_SMD:SOT-23-5_HandSoldering | http://ww1.microchip.com/downloads/en/DeviceDoc/20005791B.pdf | MCP6411T-E/OT
Collated Components:
Item | Qty | Reference(s) | Value | LibPart | Footprint | Datasheet | MPN
1 | 2 | C1, C5 | 3.3nF | device:C | Capacitors_SMD:C_0805_HandSoldering | https://www.digikey.com/product-detail/en/kemet/C0805C332KDRACAUTO/399-16654-1-ND/8110020 | C0805C332KDRACAUTO
2 | 2 | C2, C6 | 0.1uF | device:C | Capacitors_SMD:C_0805_HandSoldering | https://www.digikey.com/product-detail/en/kemet/C0805C104K3RACTU/399-1168-2-ND/411167 | C0805C104K3RACTU
3 | 3 | C3, C4, C7 | 1uF | device:C | Capacitors_SMD:C_0805_HandSoldering | https://www.digikey.com/product-detail/en/samsung-electro-mechanics/CL21F105ZBFNNNE/1276-3010-2-ND/3888668 | CL21F105ZBFNNNE
4 | 2 | C8, C9 | 1nF | device:C | Capacitors_SMD:C_0805_HandSoldering | https://www.digikey.com/product-detail/en/kemet/C0805C102J5HACAUTO/399-16591-1-ND/7943643 | C0805C102J5HACAUTO
5 | 4 | D1, D2, D3, D4 | BAV99 | device:D_x2_Serial_AKC | TO_SOT_Packages_SMD:SOT-23 | https://www.digikey.com/product-detail/en/nexperia-usa-inc/BAV99235/1727-4311-1-ND/2209921 | BAV99,235
6 | 3 | J1, J3, J4 | Screw_Terminal_1x03 | NixieSupply5vto170vDCMBoostMini-cache:Screw_Terminal_1x03 | TerminalBlock_Phoenix:TerminalBlock_Phoenix_MPT-2.54mm_3pol | https://www.digikey.com/product-detail/en/phoenix-contact/1725669/277-1274-ND/267463 | 1725669
7 | 1 | J2 | Screw_Terminal_1x02 | NixieSupply5vto170vDCMBoostMini-cache:Screw_Terminal_1x02 | TerminalBlock_Phoenix:TerminalBlock_Phoenix_MPT-2.54mm_2pol | https://www.digikey.com/product-detail/en/phoenix-contact/1725656/277-1273-ND/267462 | 1725656
8 | 2 | N1, N2 | IN-9 | nixies-us:IN-9 | nixies-us_IN-9
9 | 2 | Q1, Q3 | FDD7N25LZTM | transistors:BSP129 | TO_SOT_Packages_SMD:TO-252-2Lead | https://www.digikey.com/product-detail/en/on-semiconductor/FDD7N25LZTM/FDD7N25LZTMCT-ND/3908038 | FDD7N25LZTM
10 | 2 | Q2, Q4 | 2N7002 | transistors:2N7002 | TO_SOT_Packages_SMD:SOT-23 | https://www.digikey.com/product-detail/en/micro-commercial-co/2N7002-TP/2N7002-TPMSTR-ND/1959296 | 2N7002-TP
11 | 9 | R1, R2, R5, R6, R7, R8, R9, R10, R20 | 1k | device:R | Resistors_SMD:R_0805_HandSoldering | https://www.digikey.com/product-detail/en/yageo/RC0805FR-071KL/311-1.00KCRCT-ND/730391 | RC0805FR-071KL
12 | 2 | R3, R11 | 1k 2W | device:R | Resistors_THT:R_Axial_DIN0411_L9.9mm_D3.6mm_P12.70mm_Horizontal | https://www.digikey.com/product-detail/en/vishay-bc-components/PR02000201001JR500/PPC1.0KW-2TR-ND/596130 | PR02000201001JR500
13 | 2 | R4, R12 | 133 | device:R | Resistors_SMD:R_0805_HandSoldering | https://www.digikey.com/product-detail/en/yageo/RC0805FR-07133RL/311-133CRCT-ND/730538 | RC0805FR-07133RL
14 | 2 | R13, R14 | 220k | device:R | Resistors_SMD:R_0805_HandSoldering | https://www.digikey.com/product-detail/en/te-connectivity-passive-product/CRGCQ0805F220K/A129777CT-ND/8577609 | CRGCQ0805F220K
15 | 5 | R15, R18, R22, R23, R24 | NU | device:R | Resistors_SMD:R_0805_HandSoldering
16 | 4 | R16, R17, R19, R21 | 0 | device:R | Resistors_SMD:R_0805_HandSoldering
17 | 2 | U1, U3 | MCP6411 | linear:MCP6001 | TO_SOT_Packages_SMD:SOT-23-5_HandSoldering | http://ww1.microchip.com/downloads/en/DeviceDoc/20005791B.pdf | MCP6411T-E/OT
18 | 1 | U2 | Raspberry_PI_Zero_Header | ETAclock-cache:Raspberry_PI_Zero_Hat | etaclock:Raspberry_Pi_Zero_40pins

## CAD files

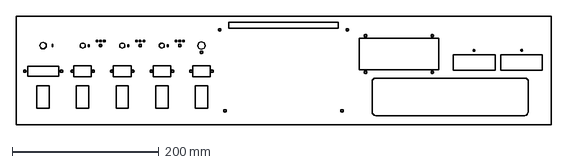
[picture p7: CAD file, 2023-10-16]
cabinet/dwgs/002_mounting_plate.dxf
730.0 x 148.0 mm

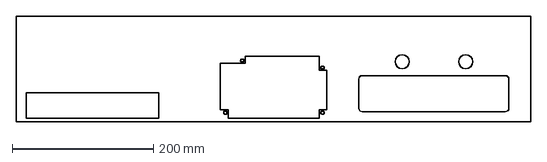
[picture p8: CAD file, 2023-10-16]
cabinet/dwgs/003_backing_plate.dxf
730.0 x 150.0 mm

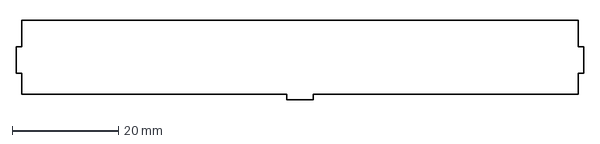
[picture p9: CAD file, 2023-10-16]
cabinet/dwgs/006_nixie_top_plate.dxf
107.0 x 15.0 mm

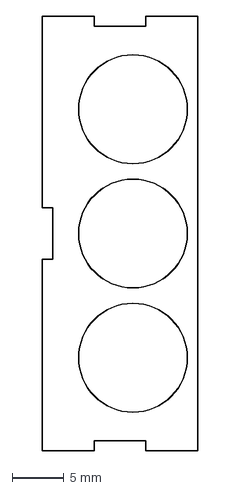
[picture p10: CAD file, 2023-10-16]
cabinet/dwgs/005_nixie_mounting_plate.dxf
15.0 x 42.0 mm

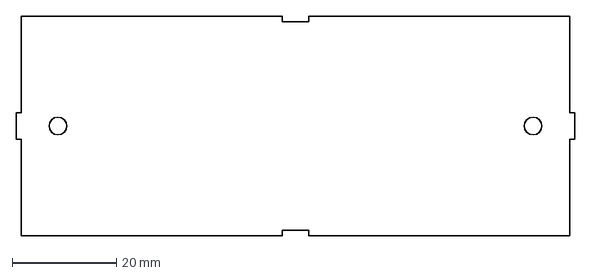
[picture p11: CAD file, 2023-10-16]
cabinet/dwgs/004_nixie_back_plate.dxf
107.0 x 42.0 mm

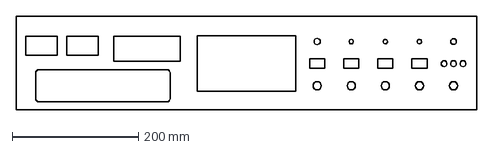
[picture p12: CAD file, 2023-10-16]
cabinet/dwgs/001_face_plate.dxf
730.0 x 148.0 mm

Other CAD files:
cabinet/f3ds/001_face_plate.f3d
cabinet/f3ds/002_mounting_plate.f3d
cabinet/f3ds/003_backing_plate.f3d
cabinet/f3ds/004_nixie_back_plate.f3d
cabinet/f3ds/005_nixie_mounting_plate.f3d
cabinet/f3ds/006_nixie_top_plate.f3d

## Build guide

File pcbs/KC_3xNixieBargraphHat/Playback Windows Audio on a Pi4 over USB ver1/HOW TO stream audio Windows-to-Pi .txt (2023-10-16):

HOW TO stream audio from Windows to Pi4 over a USB ethernet gadget connection 
version 1.0 by Charlie Laub. Released 3 SEPT 2019.

This document describes how to implement a system consisting of a Windows (7,8,10) "source" with playback on a Pi 4 over a USB ethernet gadget connection via USB-C. This does not work with any variants of the Pi 2/3 and the Pi Zero is a bit too underpowered for this task. In this embodiment, the Pi is functioning like a DAC, however, the gstreamer pipeline can be modified so the Pi also performs DSP using LADSPA plugins. 

REQUIREMENTS:
Pi 4 with power supplied via the GPIO pins (not the USB-C port!). See NOTE 1
USB-C to USB-C cable, or suitable USB-C to USB3.x adapter
A USB 3.x port on the Windows machine
Gstreamer installed on both the Windows computer and Pi 4.
Windows helper script "stream_my_audio.bat"
Bash helper script "receive_my_audio.sh"

INSTALLATION ON WINDOWS:
Download the Windows bath file "stream_my_audio.bat" to the Desktop on the Windows machine.
Install Gstreamer executable. For Windows (use MinGW 32 or 64 bit runtime installer): [url]https://gstreamer.freedesktop.org/download/[/url]
If you use the 32 bit version, you will need to edit line 72 of the batch file with the complete path to the Gstreamer executable. For the 64 bit version on my machine, to call Gstreamer I use in line 72:
  c:\gstreamer\1.0\X86_64\bin\gst-launch-1.0.exe
For the 32-bit version of Gstreamer, the path may contain X86_32 in place of X86_64. Please verify this for your installation and edit the path as necessary. You can test the call by typing in a Windows command.com window:
c:\gstreamer\1.0\X86_64\bin\gst-launch-1.0.exe --version
If the path is correct, Gstreamer will output the version number and exit.
It is strongly suggested that the Windows audio loopback device "VB-Cable" is installed and used. See:
https://www.vb-audio.com/Cable/

INSTALLATION ON RASPBERRY PI 4:
Install Gstreamer. For the Pi 4 (Debian Based) run the following commands in a terminal window:
[CODE]
sudo apt update
sudo apt install libgstreamer1.0-0 gstreamer1.0-plugins-base gstreamer1.0-plugins-good gstreamer1.0-plugins-bad gstreamer1.0-plugins-ugly gstreamer1.0-libav gstreamer1.0-doc gstreamer1.0-tools gstreamer1.0-x gstreamer1.0-alsa gstreamer1.0-gl gstreamer1.0-gtk3 gstreamer1.0-pulseaudio
[/CODE]
Download the bash helper script to the Pi. The type the command:
[CODE]chmod +x receive_my_audio.sh[/CODE]
This will make the file executable. 
On the Pi, open for editing as root the file /etc/modules
[CODE]sudo nano /etc/modules[/CODE]
Add the lines:
[CODE]dwc2
g_ether[/CODE]
Type ctrl-S to save the file, then crtl-X to exit.
On the Pi, open for editing as root the file /etc/dhcpcd.conf
[CODE]sudo nano /etc/dhcpcd.conf[/CODE]                                    
At the end of the file, add the lines:
[CODE]interface usb0
static ip_address=192.168.2.2/24
static routers=192.168.2.1
nogateway[/CODE]
Type Ctrl-s to save the file, then Crtl-x to exit the editor.
Reboot the Pi by typing
sudo reboot

INTIAL SET-UP:
Connect the ports of the two machines using the cable. This MUST be via the USB-C port on the Pi. Do not attempt to power the Pi via this connection!
If the Pi has been set up properly, Windows will install the RNDIS driver for the USB ethernet gadget connection. This will appear as a new device under Windows.
For help with the next few steps, see this page at Adafruit:
https://learn.adafruit.com/turning-your-raspberry-pi-zero-into-a-usb-gadget/ethernet-gadget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 
With the connection active, open the ethernet gadget device properties and then open the ipv4 properties.
Click the radio button "use following IP address", the set the IP address to 192.168.2.3 and the mask to 255.255.255.0. Leave the default gateway blank. 
Note, do not use the IP address shown in the Adafruit tutorial, use 192.168.2.3 instead.
NOTE: On my Windows-10 machine, the way to get to the ethernet gadget properties was different that what is shown on the Adafruit page. 
Disconnect the cable between machines, wait a few seconds, and then reconnect it. This will load the ip4 settings on the Windows machine for the RNDIS ethernet gadget driver.

Now we need to choose the sample rate and bit depth that will be streamed over this connection. This is primarily determined on the Windows machine. In gstreamer under Windows, WASAPI gets audio from the default playback device and the audio will be in the sample rate and format of that device. I use VB-Cable on my system, but you can use any playback device as long as that device supports the audio format you would like to use. Only 16 or 24 bit formats can be streamed, so choose one of these. The scripts come preconfigured for a sample rate of 96kHz and 24-bit audio, so you might start wtih that. Set your preferred audio device to this sample rate and format now. If you are using VB-Cable, this should be set both under "playback devices" and "recording devices". Audio will be resampled to this format within Windows. If you wish to use other sample rates and formats, the scripts on both machines must be edited to reflect these changes. There are sections at the top of each file where you will find the relevent parameters.

On the Pi, confirm which audio device you wish to use by typing:
[CODE]aplay -l[/CODE]
Identify the desired output card and device from the list of audio devices. 
Open the shell script on the Pi:
[CODE]nano receive_my_audio.sh[/CODE] 
Near the top, find the line:
[CODE]ALSA_output_device=hw:0,1[/CODE]
The hw device to the right of the equals sign is in the format hw:CARD#,DEVICE#. Change the value to the desired card and device that you identified from the aplay output.
If you wish to make changes to other program variables you can do this now. When you are ready. type Ctrl-s to save the file, then Crtl-x to exit the editor.

USAGE:
On the Windows machine, each time you wish to stream audio to the Pi, run the batch file. On the Pi, you can manually run the shell script when you would like to stream audio, or you can set the script to run at start up. It will respond to incoming audio data by launching gstreamer and you should hear audio.

NOTES:
1: One way to do this, and get 8 analog output channels, is to use the [URL="https://www.diyaudio.com/forums/pc-based/341590-using-raspberry-pi-4-usb-dsp-dac-post5890679.html"]HDMI extractor HAT described in this post[/URL].

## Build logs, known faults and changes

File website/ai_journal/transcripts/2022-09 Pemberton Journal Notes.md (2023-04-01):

Originally, this whole project started with the simple desire to have my sound card angled up slightly, kind of like a music studio control panel, so that it felt more like a deliberately placed part of the setup rather than an afterthought placed wherever it fit.
"Kind of like a music studio" is a common theme in this project.
Music studios, particularly older ones, have a lot to like.
They're warm spaces, designed for long periods of occupation, with very intentional layouts designed for optimal acoustics, which is both functional and ergonomic in the sense that it enables comfortable listening for long periods.
The layouts are also designed to allow efficient access to a large amount of space-consuming equipment, often where space is actually in short supply, not plentiful as you'd like it to be.
Music studios, especially older ones, also tend to be full of analogue equipment.
Whether this equipment is better is a topic for another blog, so what objective qualities do they possess that appeal to me? Heavy and solidly built.
Tactile, meaning little or no plastic, lots of wood and metal, tactile controls, and tactile feedback.
Infinite variation within a fixed range is an intriguing idea.
Analogue controls are infinitely adjustable, but a compressor is always a compressor.
Contrast this with a Raspberry Pi, or any digital device, where the range is configurable across an effectively infinite set of potential outputs, but the variation, i.e.
the resolution, is locked.
Analogue devices, then, have a kind of welcoming quality that lets you feel a more direct connection to their inner workings.
You know, this knob in particular is doing something specific somewhere in there.
Digital devices, in contrast, have a sort of impersonal obscurity.
This knob is a position output, same as all the rest, and it's taken into the mind-numbingly complex microprocessor, which does something with it.
Except sometimes it doesn't work, and you don't know why.
Digital systems do have their considerable advantages though.
They're modifiable, they're powerful, they're self-contained and easy to obtain, ready to go.
They have an incredibly wide range of potential functions.
They're easier to personalize, easier to design, at least for some functions.
They're more consistent, as in they have no variation in electrical outputs due to components, whereas an analog system might be different to another supposedly identical one because of tiny variations as a result of manufacturing different electrical components like resistors, capacitors, etc.
In other words, analog devices are much nicer, but digital devices are much easier to actually make.
The goal then is to create a device that matches as much of the warmth of purpose-built analog devices with the ease of use and flexibility of digital devices.
Wherever possible, the advantages of one should be leveraged to compensate for the disadvantages of the other.

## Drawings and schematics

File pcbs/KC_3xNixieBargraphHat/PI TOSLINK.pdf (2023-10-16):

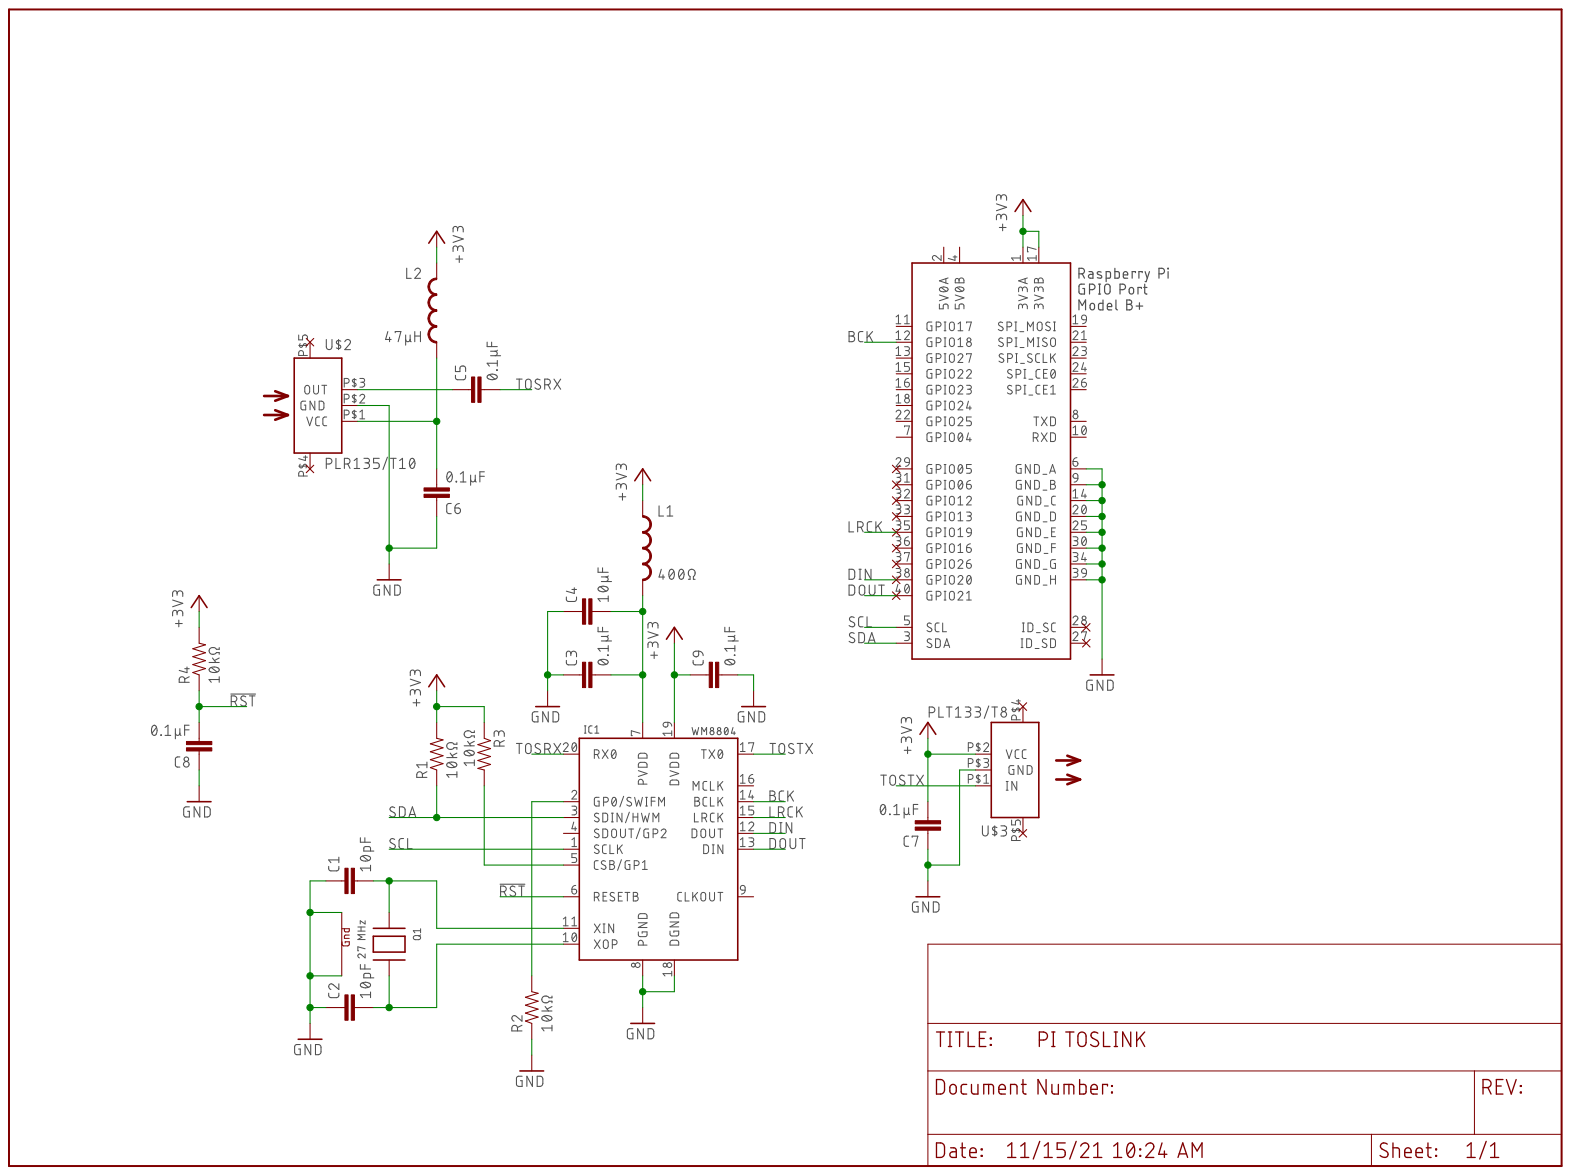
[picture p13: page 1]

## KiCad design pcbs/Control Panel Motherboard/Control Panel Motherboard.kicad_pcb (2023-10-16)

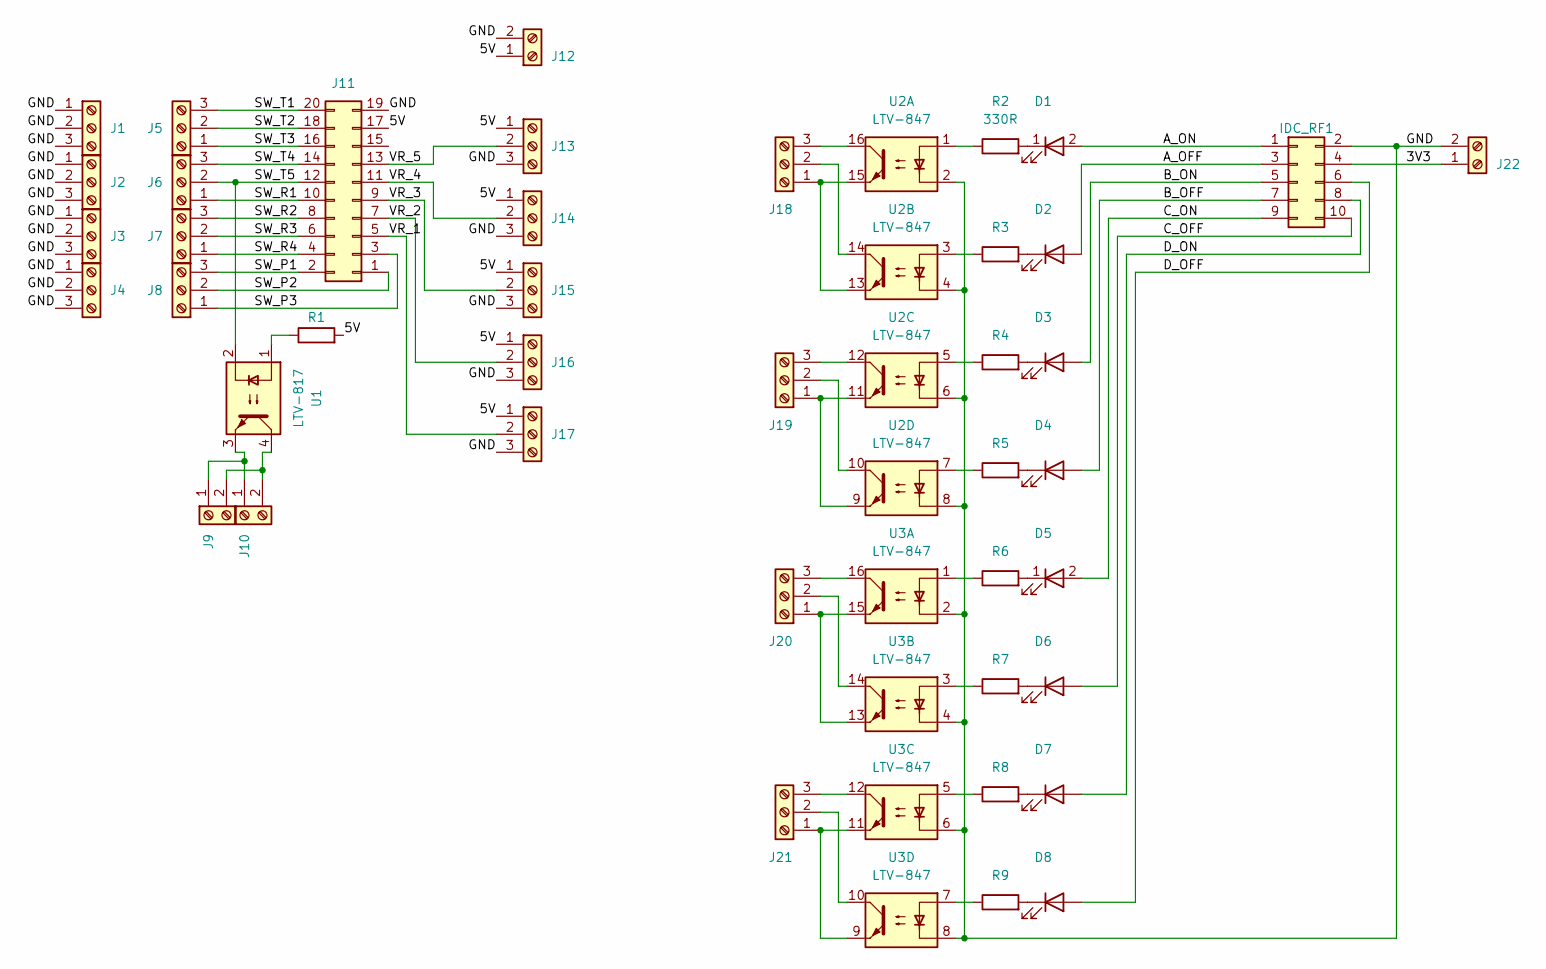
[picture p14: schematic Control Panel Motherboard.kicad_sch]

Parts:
D1, D2, D3, D4, D5, D6, D7, D8: LED; LED_D3.0mm
IDC_RF1: IDC_SW; IDC-Header_2x05_P2.54mm_Vertical
J1, J2, J3, J4, J5, J6, J7, J8, J13, J14, J15, J16, J17, J18, J19, J20, J21: Screw_Terminal_01x03; TerminalBlock_bornier-3_P5.08mm
J9, J10, J12, J22: Screw_Terminal_01x02; TerminalBlock_bornier-2_P5.08mm
J11: J_IDC_SW_IN; IDC-Header_2x10_P2.54mm_Vertical
R1, R2, R3, R4, R5, R6, R7, R8, R9: 330R; R_Axial_DIN0207_L6.3mm_D2.5mm_P7.62mm_Horizontal
U1: LTV-817; DIP-4_W7.62mm
U2, U3: LTV-847; DIP-16_W7.62mm

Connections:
/3V3: IDC_RF1.4, J22.1
/5V: J11.17, J12.1, J13.1, J14.1, J15.1, J16.1, J17.1, R1.2
/A_OFF: D2.2 (A), IDC_RF1.3
/A_ON: D1.2 (A), IDC_RF1.1
/B_OFF: D4.2 (A), IDC_RF1.7
/B_ON: D3.2 (A), IDC_RF1.5
/C_OFF: D6.2 (A), IDC_RF1.10
/C_ON: D5.2 (A), IDC_RF1.9
/D_OFF: D8.2 (A), IDC_RF1.6
/D_ON: D7.2 (A), IDC_RF1.8
/GND: IDC_RF1.2, J1.1, J1.2, J1.3, J2.1, J2.2, J2.3, J3.1, J3.2, J3.3, J4.1, J4.2, J4.3, J11.19, J12.2, J13.3, J14.3, J15.3, J16.3, J17.3, J22.2, U2.2, U2.4, U2.6, U2.8, U3.2, U3.4, U3.6, U3.8
/SW_P1: J8.3, J11.2
/SW_P2: J8.2, J11.1
/SW_P3: J8.1, J11.3
/SW_R1: J6.1, J11.10
/SW_R2: J7.3, J11.8
/SW_R3: J7.2, J11.6
/SW_R4: J7.1, J11.4
/SW_T1: J5.3, J11.20
/SW_T2: J5.2, J11.18
/SW_T3: J5.1, J11.16
/SW_T4: J6.3, J11.14
/SW_T5: J6.2, J11.12, U1.2
/VR_1: J11.5, J17.2
/VR_2: J11.7, J16.2
/VR_3: J11.9, J15.2
/VR_4: J11.11, J14.2
/VR_5: J11.13, J13.2
unnamed: D1.1 (K), R2.2
unnamed: D2.1 (K), R3.2
unnamed: D3.1 (K), R4.2
unnamed: D4.1 (K), R5.2
unnamed: D5.1 (K), R6.2
unnamed: D6.1 (K), R7.2
unnamed: D7.1 (K), R8.2
unnamed: D8.1 (K), R9.2
unnamed: J9.1, J10.1, U1.3
unnamed: J9.2, J10.2, U1.4
unnamed: J18.1, U2.13, U2.15
unnamed: J18.2, U2.14
unnamed: J18.3, U2.16
unnamed: J19.1, U2.9, U2.11
unnamed: J19.2, U2.10
unnamed: J19.3, U2.12
unnamed: J20.1, U3.13, U3.15
unnamed: J20.2, U3.14
unnamed: J20.3, U3.16
unnamed: J21.1, U3.9, U3.11
unnamed: J21.2, U3.10
unnamed: J21.3, U3.12
unnamed: R1.1, U1.1
unnamed: R2.1, U2.1
unnamed: R3.1, U2.3
unnamed: R4.1, U2.5
unnamed: R5.1, U2.7
unnamed: R6.1, U3.1
unnamed: R7.1, U3.3
unnamed: R8.1, U3.5
unnamed: R9.1, U3.7

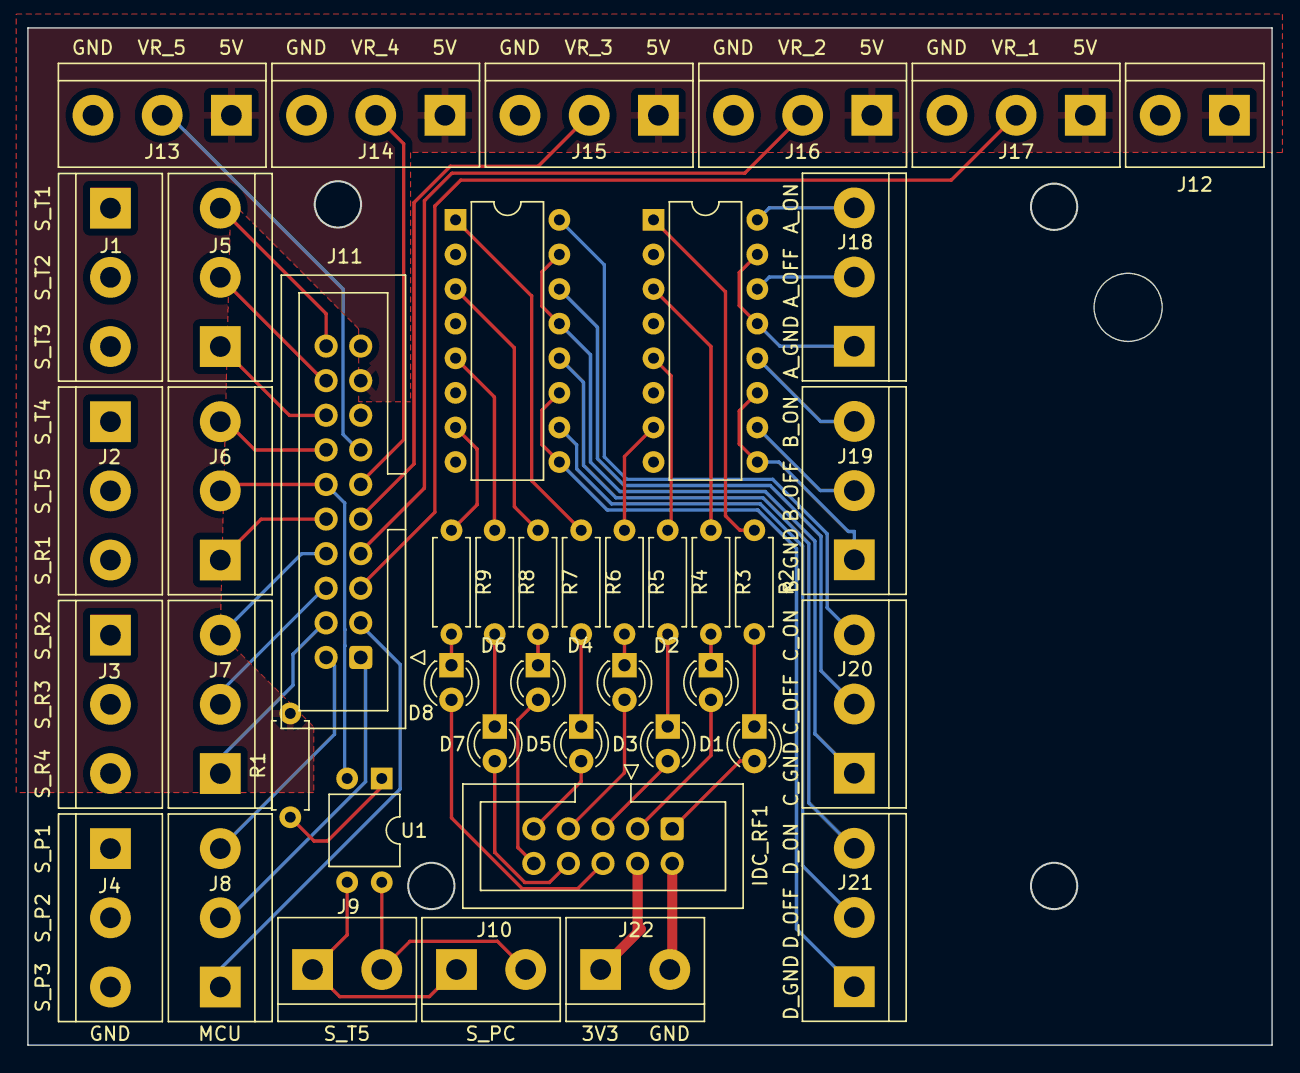
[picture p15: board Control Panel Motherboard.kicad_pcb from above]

Board: 2 copper layers, 91.3 x 74.7 mm, 43 parts (0 on the bottom side), 59 nets.

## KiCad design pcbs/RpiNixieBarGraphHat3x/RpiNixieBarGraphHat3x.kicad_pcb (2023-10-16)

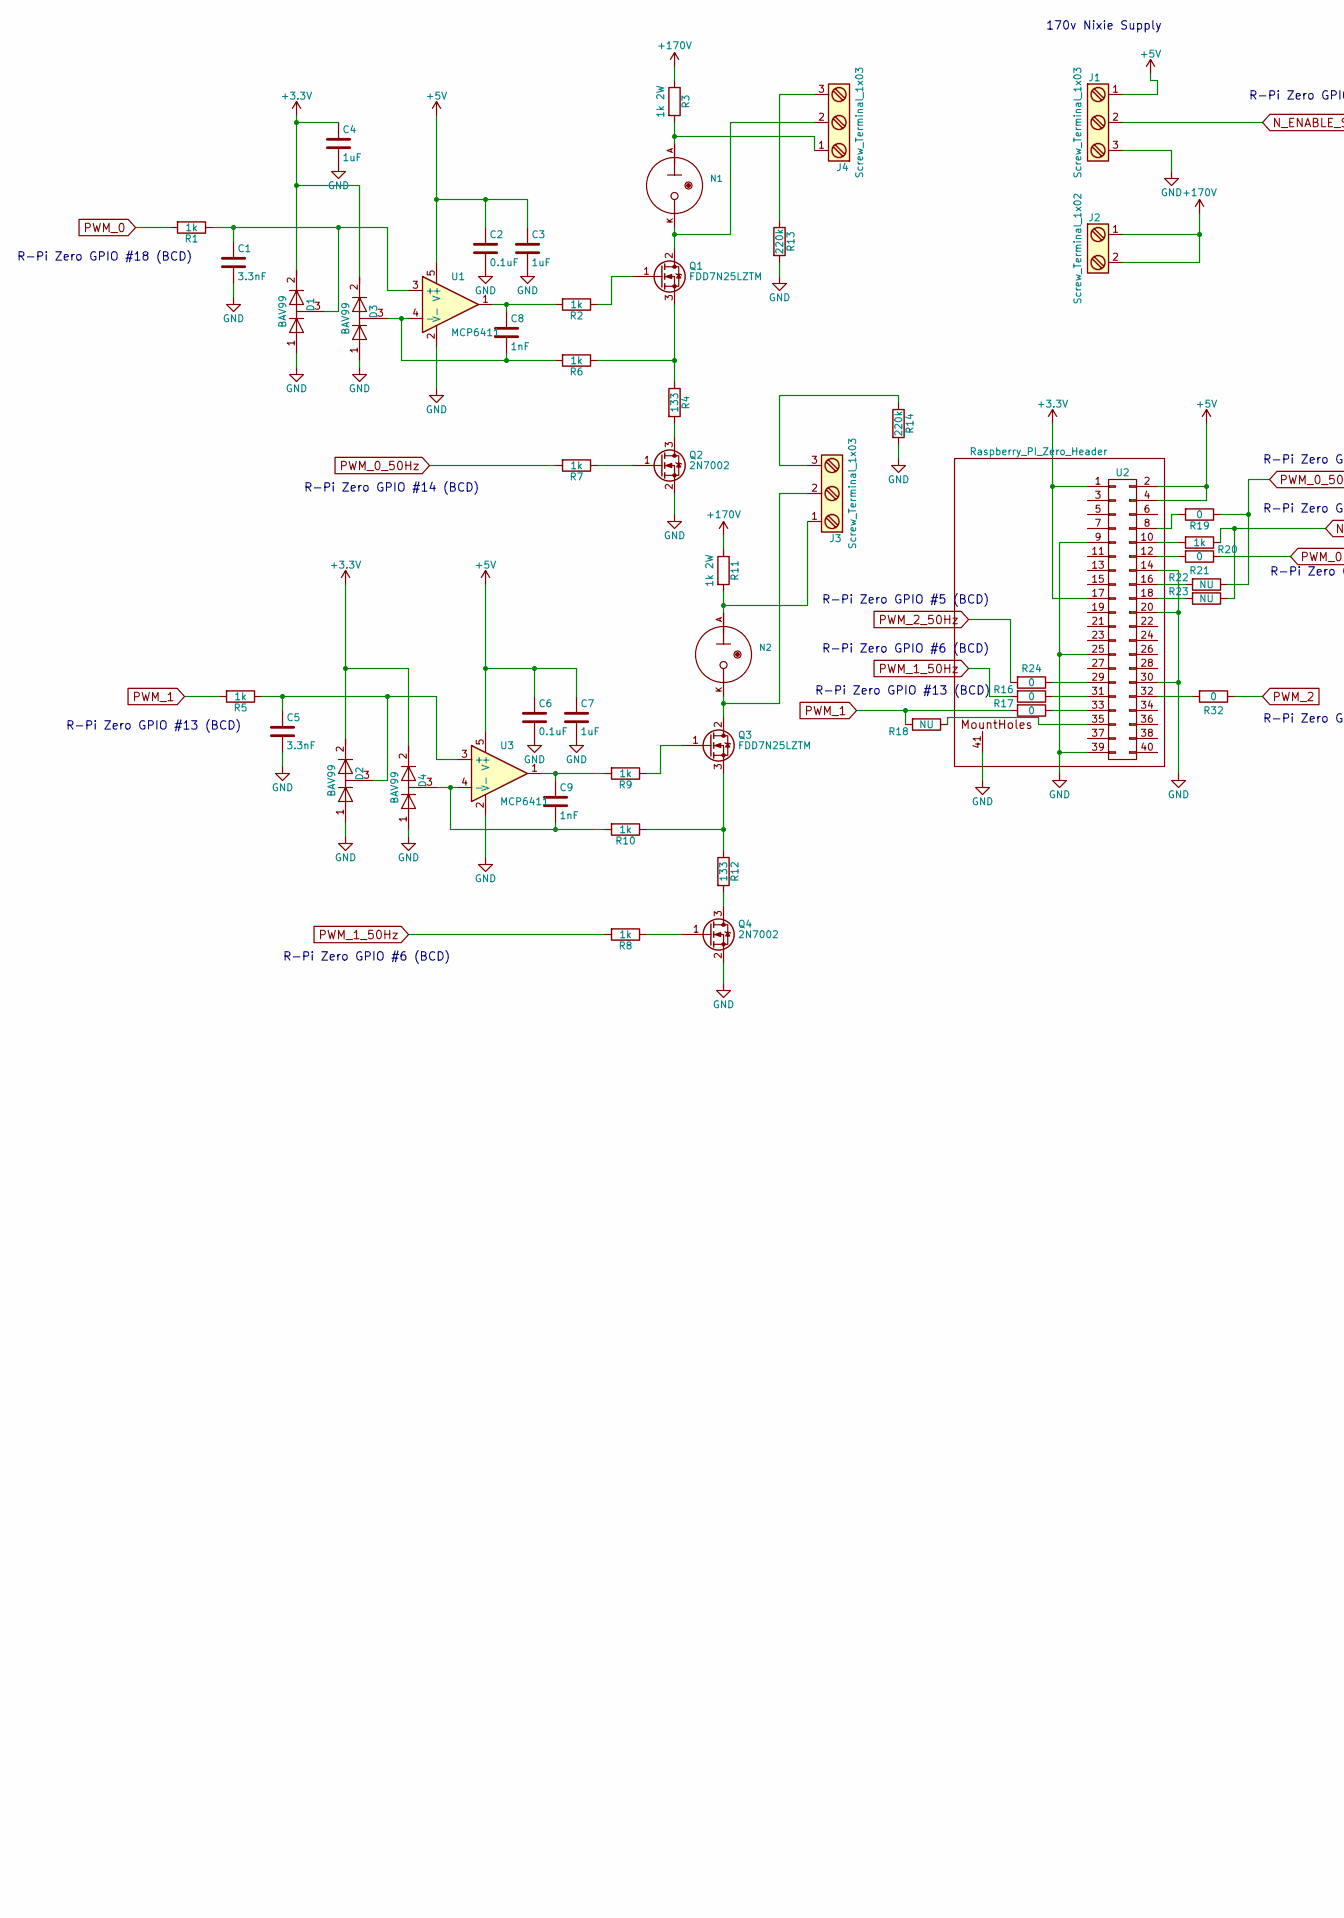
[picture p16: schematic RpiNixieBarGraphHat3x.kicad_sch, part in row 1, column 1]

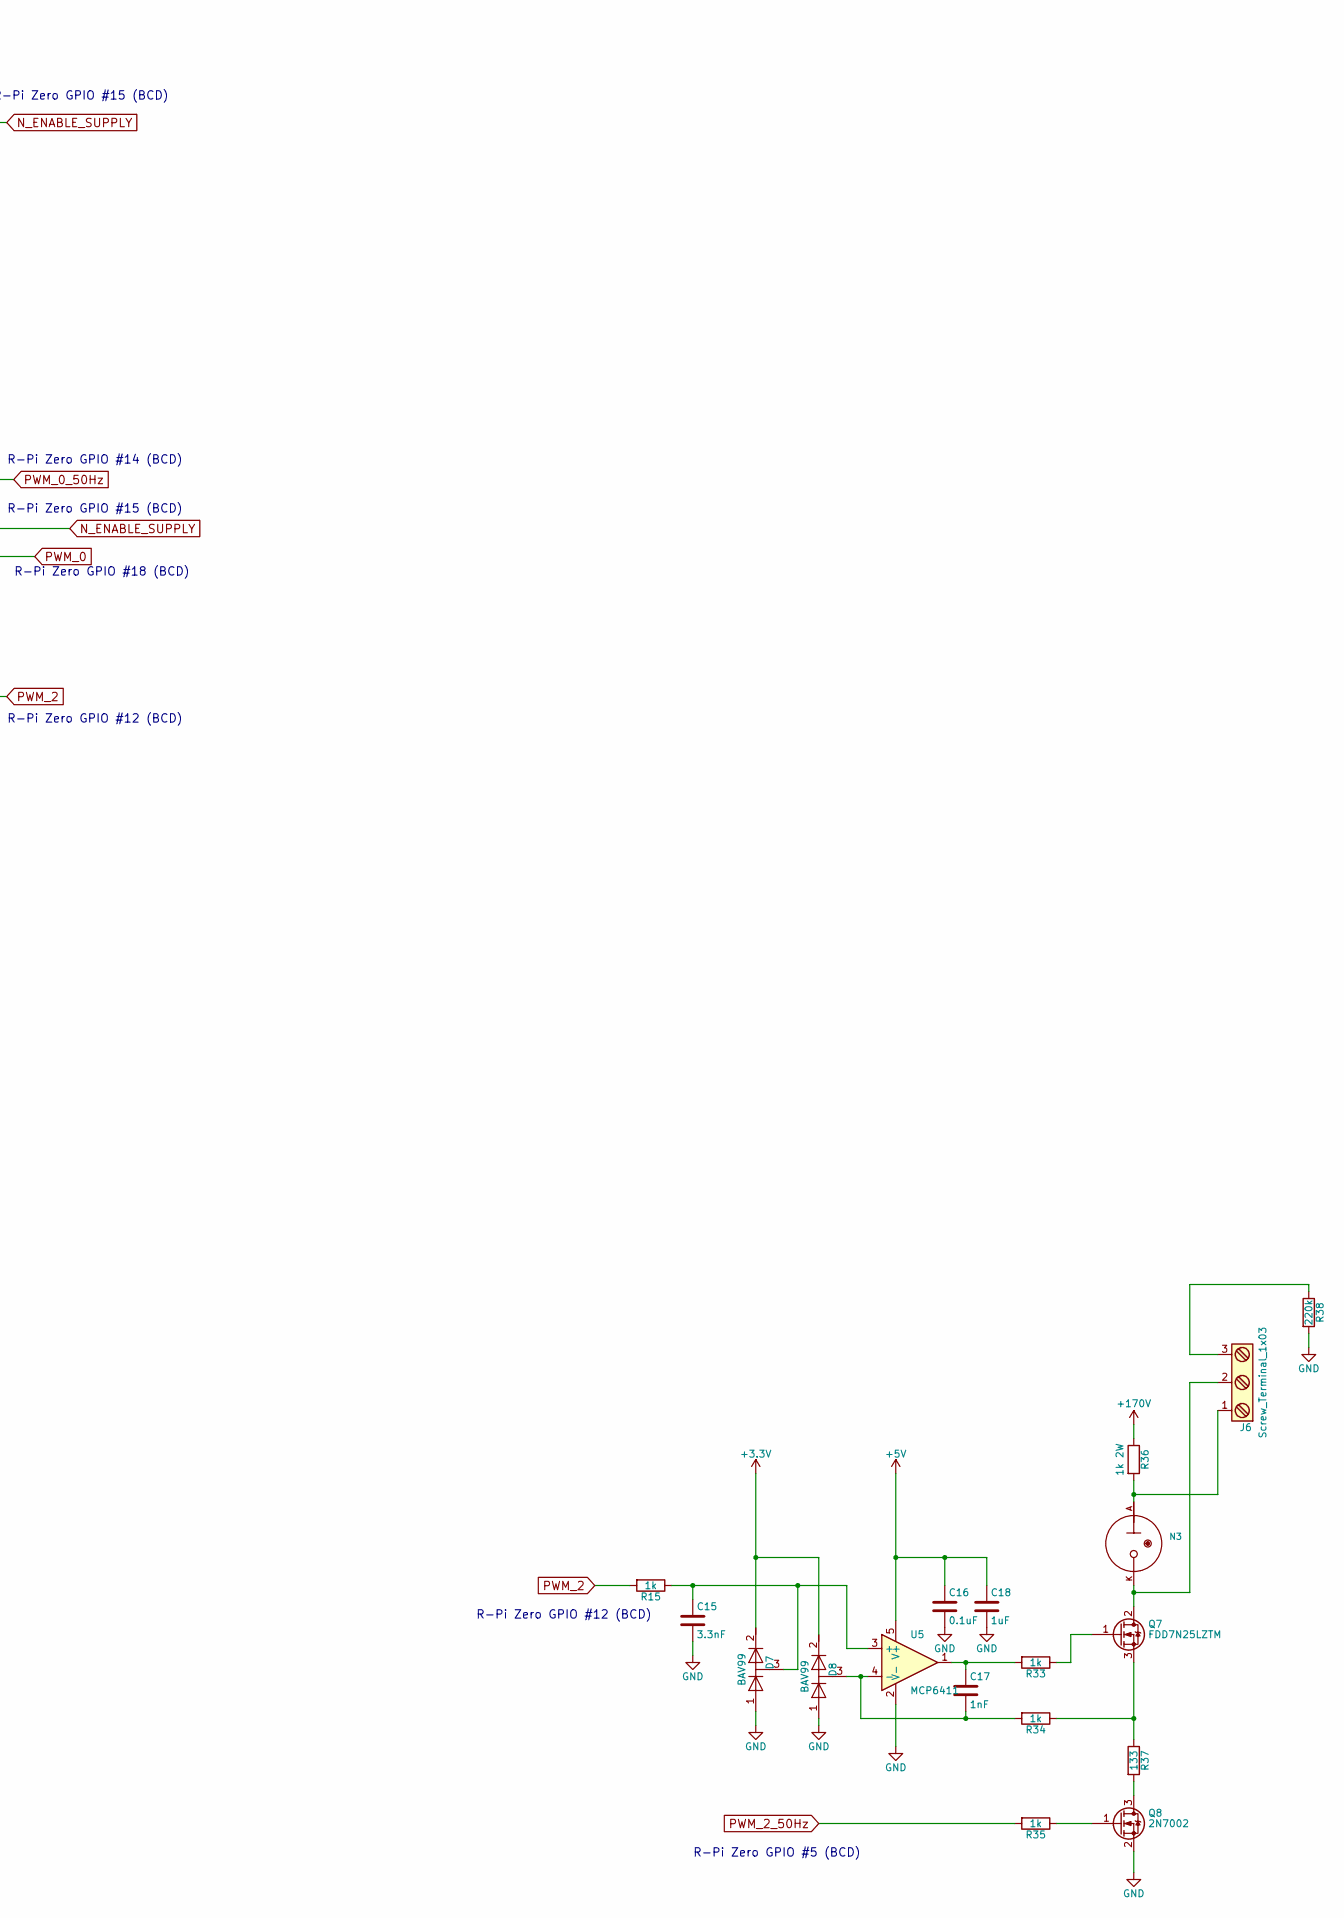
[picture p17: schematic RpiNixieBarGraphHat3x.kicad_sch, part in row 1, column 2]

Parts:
C1, C5, C15: 3.3nF; C_0805_2012Metric_Pad1.18x1.45mm_HandSolder; MPN C0805C332KDRACAUTO
C2, C6, C16: 0.1uF; C_0805_2012Metric_Pad1.18x1.45mm_HandSolder; MPN C0805C104K3RACTU
C3, C4, C7, C18: 1uF; C_0805_2012Metric_Pad1.18x1.45mm_HandSolder; MPN CL21F105ZBFNNNE
C8, C9, C17: 1nF; C_0805_2012Metric_Pad1.18x1.45mm_HandSolder; MPN C0805C102J5HACAUTO
D1, D2, D3, D4, D7, D8: BAV99; SOT-23; MPN BAV99,235
J1, J3, J4, J6: Screw_Terminal_1x03; TerminalBlock_Phoenix_MPT-0,5-3-2.54_1x03_P2.54mm_Horizontal; MPN 1725669
J2: Screw_Terminal_1x02; TerminalBlock_Phoenix_MPT-0,5-3-2.54_1x02_P2.54mm_Horizontal; MPN 1725656
N1, N2, N3: IN-9; nixies-us_IN-9
Q1, Q3, Q7: FDD7N25LZTM; TO-252-2; MPN FDD7N25LZTM
Q2, Q4, Q8: 2N7002; SOT-23; MPN 2N7002-TP
R1, R5, R6, R7, R8, R10, R15, R34, R35: 1k; R_0805_2012Metric_Pad1.20x1.40mm_HandSolder; MPN RC0805FR-071KL
R2, R9, R33: 1k; R_0805_2012Metric_Pad1.20x1.40mm_HandSolder; MPN RC0805FR-078K2L
R3, R11, R36: 1k 2W; R_Axial_DIN0411_L9.9mm_D3.6mm_P12.70mm_Horizontal; MPN PR02000201001JR500
R4, R12, R37: 133; R_0805_2012Metric_Pad1.20x1.40mm_HandSolder; MPN RC0805FR-07133RL
R13, R14, R38: 220k; R_0805_2012Metric_Pad1.20x1.40mm_HandSolder; MPN CRGCQ0805F220K
R16, R17, R19, R21, R24, R32: 0; R_0805_2012Metric_Pad1.20x1.40mm_HandSolder
R18, R22, R23: NU; R_0805_2012Metric_Pad1.20x1.40mm_HandSolder
R20: 1k; R_0805_2012Metric_Pad1.20x1.40mm_HandSolder
U1, U3, U5: MCP6411; SOT-23-5_HandSoldering; MPN MCP6411T-E/OT
U2: Raspberry_PI_Zero_Header; Raspberry_Pi_Zero_40pins

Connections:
+3V3: C4.1, D1.2 (K), D2.2 (K), D3.2 (K), D4.2 (K), D7.2 (K), D8.2 (K), U2.1, U2.17
+5V: C2.1, C3.1, C6.1, C7.1, C16.1, C18.1, J1.1, U1.5 (V+), U2.2, U2.4, U3.5 (V+), U5.5 (V+)
+170V: J2.1, J2.2, R3.1, R11.1, R36.1
GND: C1.2, C2.2, C3.2, C4.2, C5.2, C6.2, C7.2, C15.2, C16.2, C18.2, D1.1 (A), D2.1 (A), D3.1 (A), D4.1 (A), D7.1 (A), D8.1 (A), J1.3, Q2.2 (S), Q4.2 (S), Q8.2 (S), R13.2, R14.2, R38.2, U1.2 (V-), U2.9, U2.14, U2.20, U2.25, U2.30, U2.39, U2.41 (MountHoles), U3.2 (V-), U5.2 (V-)
N_ENABLE_SUPPLY: J1.2, R20.1, R23.1
unnamed: C8.1, R2.2, U1.1
unnamed: C9.1, R9.2, U3.1
unnamed: C17.1, R33.2, U5.1
unnamed: C1.1, D1.3 (common), R1.1, U1.3 (+)
unnamed: C5.1, D2.3 (common), R5.1, U3.3 (+)
unnamed: C8.2, D3.3 (common), R6.2, U1.4 (-)
unnamed: C9.2, D4.3 (common), R10.2, U3.4 (-)
unnamed: C15.1, D7.3 (common), R15.1, U5.3 (+)
unnamed: C17.2, D8.3 (common), R34.2, U5.4 (-)
unnamed: J3.1, N2.A, R11.2
unnamed: J3.3, R14.1
unnamed: J4.1, N1.A, R3.2
unnamed: J4.3, R13.1
unnamed: J6.1, N3.A, R36.2
unnamed: J6.3, R38.1
unnamed: J4.2, N1.K, Q1.2 (D)
unnamed: Q1.1 (G), R2.1
unnamed: Q1.3 (S), R4.1, R6.1
unnamed: Q2.3 (D), R4.2
unnamed: Q2.1 (G), R7.1
unnamed: J3.2, N2.K, Q3.2 (D)
unnamed: Q3.1 (G), R9.1
unnamed: Q3.3 (S), R10.1, R12.1
unnamed: Q4.3 (D), R12.2
unnamed: Q4.1 (G), R8.1
unnamed: J6.2, N3.K, Q7.2 (D)
unnamed: Q7.1 (G), R33.1
unnamed: Q7.3 (S), R34.1, R37.1
unnamed: Q8.3 (D), R37.2
unnamed: Q8.1 (G), R35.1
unnamed: R19.2, U2.8
unnamed: R20.2, U2.10
unnamed: R21.2, U2.12
unnamed: R22.2, U2.16
unnamed: R23.2, U2.18
unnamed: R24.1, U2.29
unnamed: R16.1, U2.31
unnamed: R32.2, U2.32
unnamed: R17.1, U2.33
unnamed: R18.1, U2.35
PWM_0: R1.2, R21.1
PWM_0_50Hz: R7.2, R19.1, R22.1
PWM_1: R5.2, R17.2, R18.2
PWM_1_50Hz: R8.2, R16.2
PWM_2: R15.2, R32.1
PWM_2_50Hz: R24.2, R35.2

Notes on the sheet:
R-Pi Zero GPIO #18 (BCD)
R-Pi Zero GPIO #15 (BCD)
R-Pi Zero GPIO #5 (BCD)
R-Pi Zero GPIO #6 (BCD)
R-Pi Zero GPIO #12 (BCD)
R-Pi Zero GPIO #14 (BCD)
R-Pi Zero GPIO #13 (BCD)
170v Nixie Supply

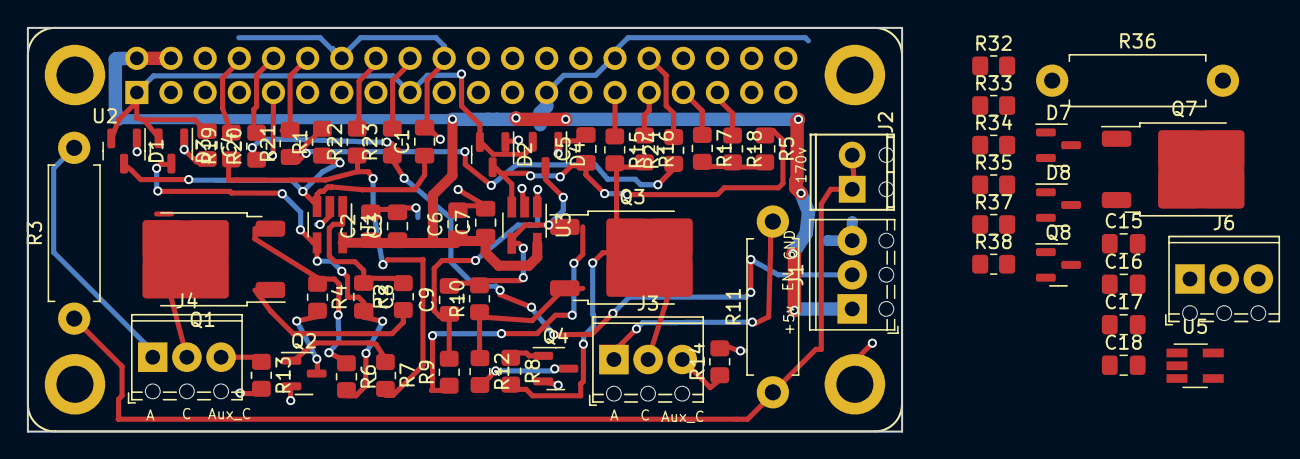
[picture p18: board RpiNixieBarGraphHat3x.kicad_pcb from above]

Board: 2 copper layers, 65.0 x 30.0 mm, 65 parts (0 on the bottom side), 51 nets.

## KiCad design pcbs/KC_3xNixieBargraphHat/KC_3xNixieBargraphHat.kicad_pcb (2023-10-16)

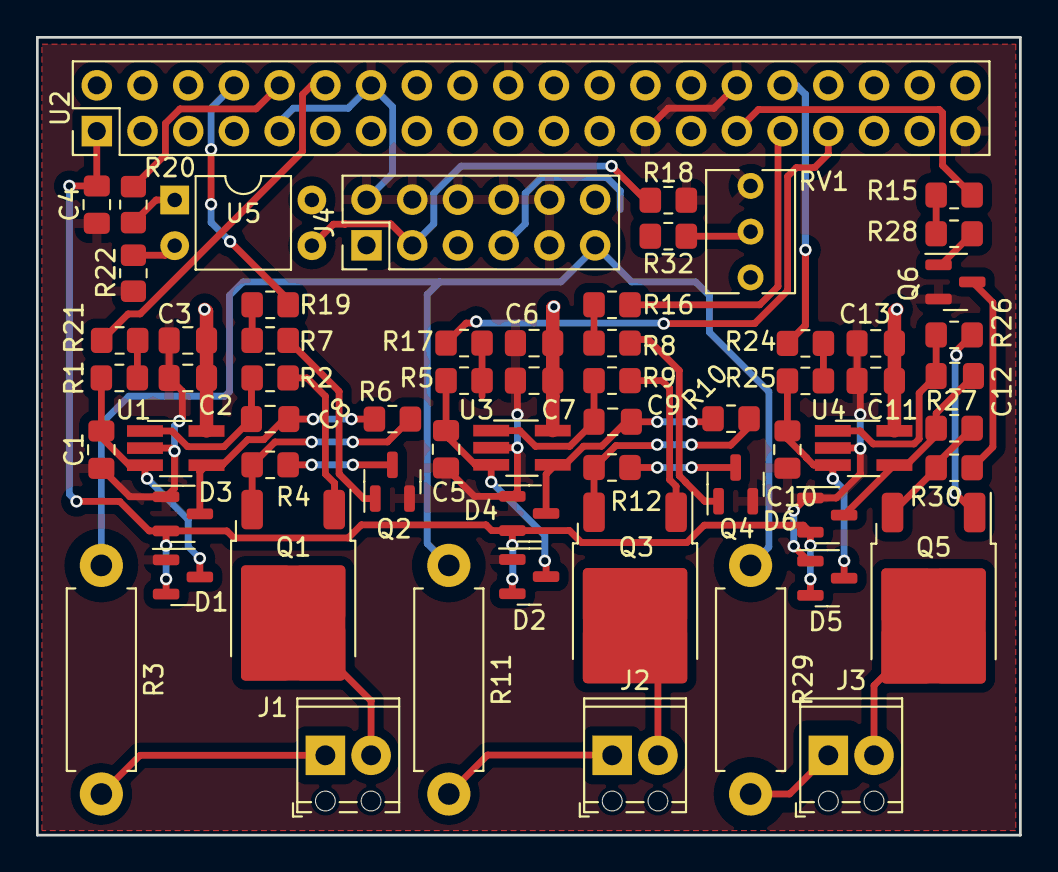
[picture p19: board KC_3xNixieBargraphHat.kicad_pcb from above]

Board: 2 copper layers, 54.6 x 44.3 mm, 63 parts (0 on the bottom side), 50 nets.

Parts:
C1, C5, C10: 3.3nF; C_0805_2012Metric_Pad1.18x1.45mm_HandSolder
C2, C6, C11: 0.1uF; C_0805_2012Metric_Pad1.18x1.45mm_HandSolder
C3, C4, C7, C13: 1uF; C_0805_2012Metric_Pad1.18x1.45mm_HandSolder
C8, C9, C12: 1nF; C_0805_2012Metric_Pad1.18x1.45mm_HandSolder
D1, D2, D3, D4, D5, D6: BAV99; SOT-23
J1, J2, J3: Screw_Terminal_1x02; TerminalBlock_Phoenix_MPT-0,5-2-2.54_1x02_P2.54mm_Horizontal
J4: Conn_02x06; PinHeader_2x06_P2.54mm_Vertical
Q1, Q3, Q5: FDD7N25LZTM; TO-252-2
Q2, Q4, Q6: 2N7002; SOT-23
R1, R2, R5, R6, R7, R8, R9, R10, R20, R25, R26, R27, R28: 1k; R_0805_2012Metric_Pad1.20x1.40mm_HandSolder
R3, R11, R29: 1k 2W; R_Axial_DIN0411_L9.9mm_D3.6mm_P12.70mm_Horizontal
R4, R12, R30: 133; R_0805_2012Metric_Pad1.20x1.40mm_HandSolder
R15, R16, R17, R19, R21, R24: 0; R_0805_2012Metric_Pad1.20x1.40mm_HandSolder
R18: 100k; R_0805_2012Metric_Pad1.20x1.40mm_HandSolder
R22: 330; R_0805_2012Metric_Pad1.20x1.40mm_HandSolder
R32: 47k; R_0805_2012Metric_Pad1.20x1.40mm_HandSolder
RV1: 5k; Potentiometer_Vishay_T73XW_Horizontal
U1, U3, U4: MCP6411; TSOT-23-5_HandSoldering
U2: Raspberry_PI_Zero_Header; PinHeader_2x20_P2.54mm_Vertical
U5: LTV-817; DIP-4_W7.62mm

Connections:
+3V3: C4.1, D1.2 (K), D2.2 (K), D3.2 (K), D4.2 (K), D5.2 (K), D6.2 (K), U2.1, U2.17
+5V: C2.1, C3.1, C6.1, C7.1, C11.1, C13.1, J4.1, U1.5 (V+), U2.2, U2.4, U3.5 (V+), U4.5 (V+), U5.4
+170V: J4.11, R3.1, R11.1, R29.1
/ENABLE: J4.3, R18.2, U5.3
/N/C: J4.5, J4.12
/R_ADJUST: J4.7, R32.2
GND: C1.2, C2.2, C3.2, C4.2, C5.2, C6.2, C7.2, C10.2, C11.2, C13.2, D1.1 (A), D2.1 (A), D3.1 (A), D4.1 (A), D5.1 (A), D6.1 (A), J4.2, J4.4, J4.6, J4.8, J4.9, J4.10, Q2.2 (S), Q4.2 (S), Q6.2 (S), R18.1, R22.2, RV1.1, U1.2 (V-), U2.9, U2.14, U2.20, U2.25, U2.30, U2.39, U3.2 (V-), U4.2 (V-)
N_ENABLE_SUPPLY: R20.1, U5.1
unnamed: C8.1, R2.2, U1.1
unnamed: C9.1, R9.2, U3.1
unnamed: C12.1, R26.2, U4.1
unnamed: C1.1, D1.3 (common), R1.1, U1.3 (+)
unnamed: C5.1, D2.3 (common), R5.1, U3.3 (+)
unnamed: C8.2, D3.3 (common), R6.2, U1.4 (-)
unnamed: C9.2, D4.3 (common), R10.2, U3.4 (-)
unnamed: C10.1, D5.3 (common), R25.1, U4.3 (+)
unnamed: C12.2, D6.3 (common), R27.2, U4.4 (-)
unnamed: J1.1, R3.2
unnamed: J2.1, R11.2
unnamed: J3.1, R29.2
unnamed: J1.2, Q1.2 (D)
unnamed: Q1.1 (G), R2.1
unnamed: Q1.3 (S), R4.1, R6.1
unnamed: Q2.3 (D), R4.2
unnamed: Q2.1 (G), R7.1
unnamed: J2.2, Q3.2 (D)
unnamed: Q3.1 (G), R9.1
unnamed: Q3.3 (S), R10.1, R12.1
unnamed: Q4.3 (D), R12.2
unnamed: Q4.1 (G), R8.1
unnamed: J3.2, Q5.2 (D)
unnamed: Q5.1 (G), R26.1
unnamed: Q5.3 (S), R27.1, R30.1
unnamed: Q6.3 (D), R30.2
unnamed: Q6.1 (G), R28.1
unnamed: R22.1, U5.2
unnamed: R32.1, RV1.2
unnamed: R19.2, U2.8
unnamed: R20.2, U2.10
unnamed: R21.1, U2.12
unnamed: R15.1, U2.29
unnamed: R16.1, U2.31
unnamed: R24.2, U2.32
unnamed: R17.1, U2.33
PWM_0: R1.2, R21.2
PWM_0_50Hz: R7.2, R19.1
PWM_1: R5.2, R17.2
PWM_1_50Hz: R8.2, R16.2
PWM_2: R24.1, R25.2
PWM_2_50Hz: R15.2, R28.2

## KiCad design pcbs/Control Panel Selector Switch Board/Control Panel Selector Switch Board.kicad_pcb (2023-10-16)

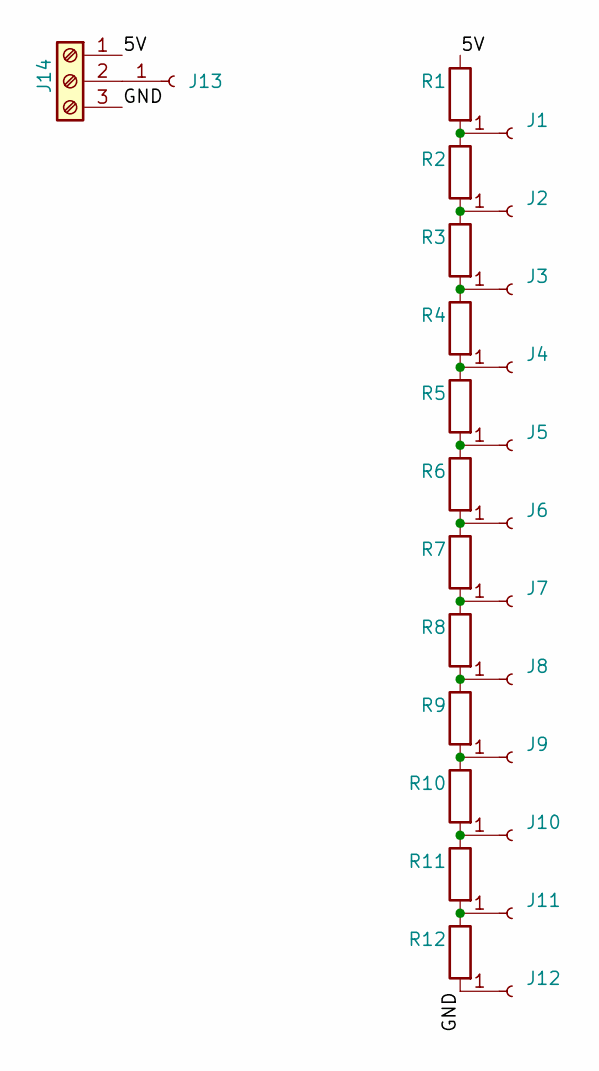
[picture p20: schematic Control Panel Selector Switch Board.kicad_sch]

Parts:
J1, J2, J3, J4, J5, J6, J7, J8, J9, J10, J11, J12, J13: Conn_01x01_Female; Pin_D1.0mm_L10.0mm
J14: Screw_Terminal_01x03; TerminalBlock_bornier-3_P5.08mm
R1, R2, R3, R4, R5, R6, R7, R8, R9, R10, R11, R12: 330R; R_Axial_DIN0204_L3.6mm_D1.6mm_P5.08mm_Horizontal

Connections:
/5V: J14.1, R1.1
/GND: J12.1, J14.3, R12.2
unnamed: J1.1, R1.2, R2.1
unnamed: J2.1, R2.2, R3.1
unnamed: J3.1, R3.2, R4.1
unnamed: J4.1, R4.2, R5.1
unnamed: J5.1, R5.2, R6.1
unnamed: J6.1, R6.2, R7.1
unnamed: J7.1, R7.2, R8.1
unnamed: J8.1, R8.2, R9.1
unnamed: J9.1, R9.2, R10.1
unnamed: J10.1, R10.2, R11.1
unnamed: J11.1, R11.2, R12.1
unnamed: J13.1, J14.2

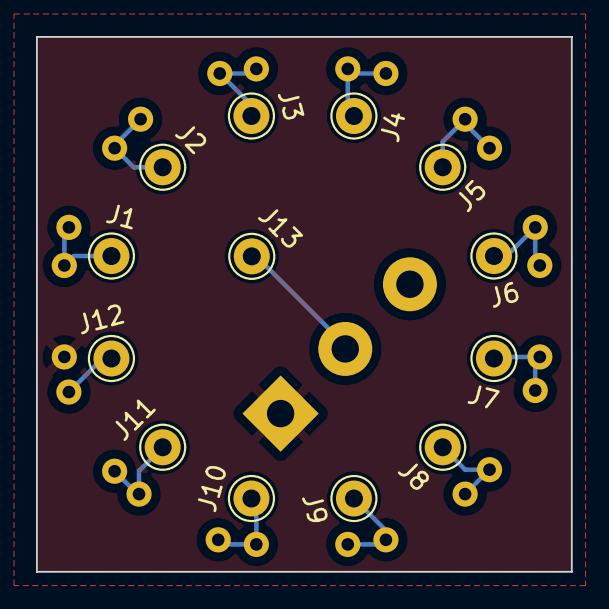
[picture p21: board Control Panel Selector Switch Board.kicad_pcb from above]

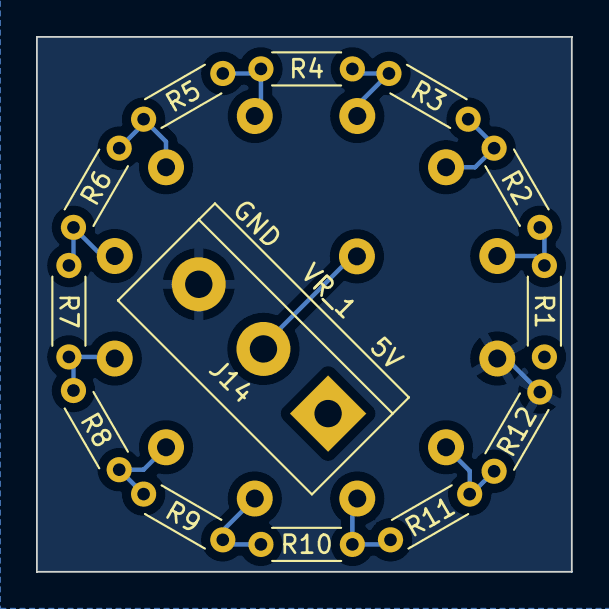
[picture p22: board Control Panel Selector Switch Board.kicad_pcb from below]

Board: 2 copper layers, 29.7 x 29.7 mm, 26 parts (13 on the bottom side), 14 nets.

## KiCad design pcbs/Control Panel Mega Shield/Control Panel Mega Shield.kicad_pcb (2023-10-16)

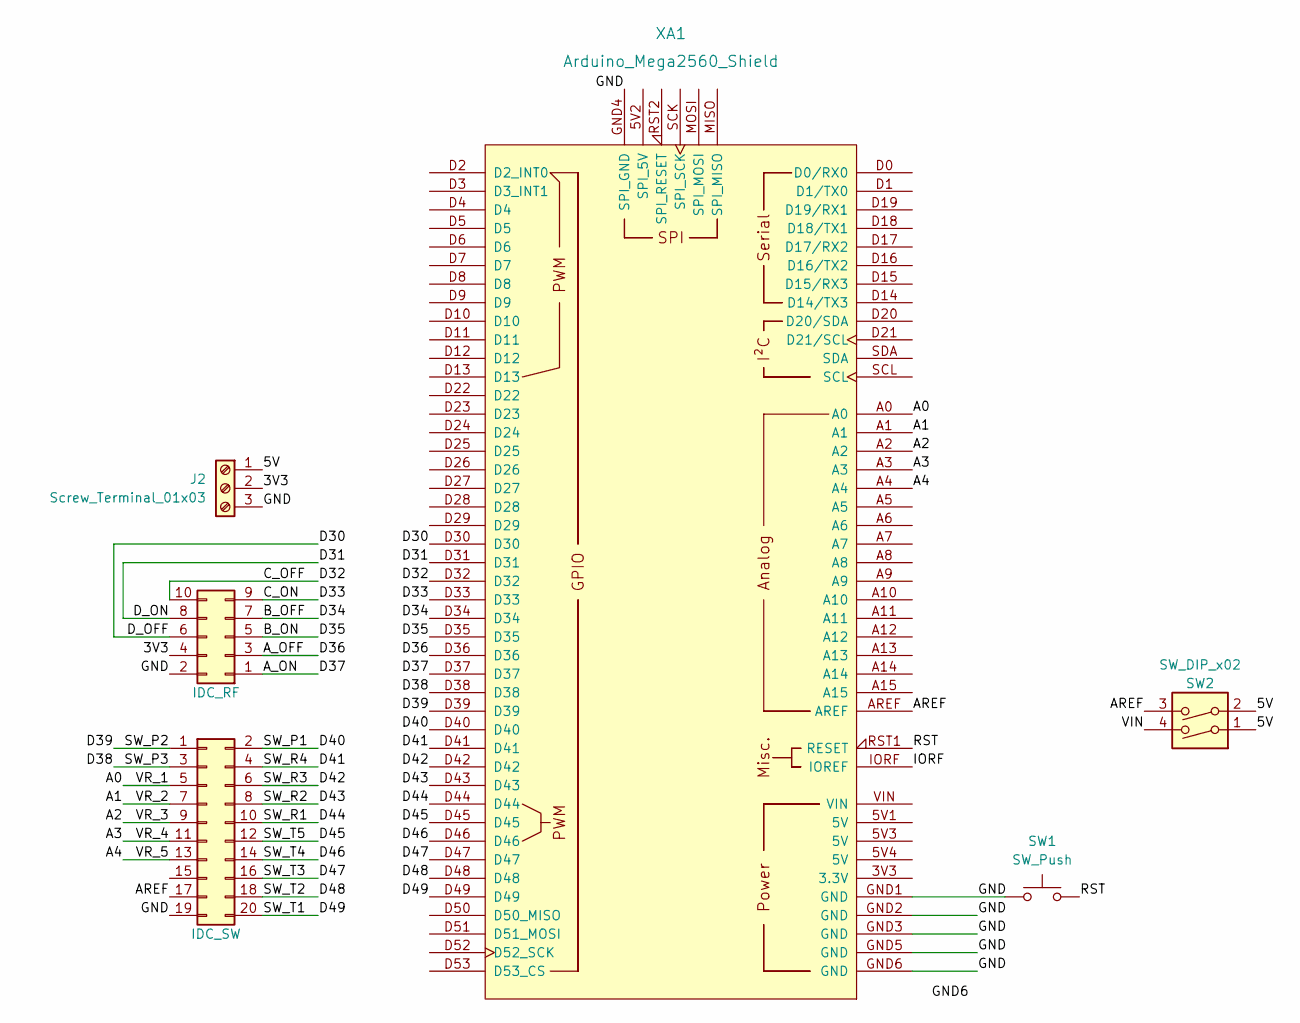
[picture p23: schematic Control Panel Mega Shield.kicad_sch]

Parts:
J1: IDC_SW; IDC-Header_2x10_P2.54mm_Vertical
J2: Screw_Terminal_01x03; TerminalBlock_bornier-3_P5.08mm
J3: IDC_RF; IDC-Header_2x05_P2.54mm_Vertical
SW1: SW_Push; SW_PUSH_6mm_H5mm
SW2: SW_DIP_x02; SW_DIP_SPSTx02_Slide_9.78x7.26mm_W7.62mm_P2.54mm
XA1: Arduino_Mega2560_Shield

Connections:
/3V3: J2.2, J3.4
/5V: J2.1, SW2.1, SW2.2
/A0: J1.5, XA1.A0
/A1: J1.7, XA1.A1
/A2: J1.9, XA1.A2
/A3: J1.11, XA1.A3
/A4: J1.13, XA1.A4
/AREF: J1.17, SW2.3, XA1.AREF
/A_OFF: J3.3, XA1.D36
/A_ON: J3.1, XA1.D37
/B_OFF: J3.7, XA1.D34
/B_ON: J3.5, XA1.D35
/C_OFF: J3.10, XA1.D32
/C_ON: J3.9, XA1.D33
/D30: J3.6, XA1.D30
/D31: J3.8, XA1.D31
/D38: J1.3, XA1.D38
/D39: J1.1, XA1.D39
/D40: J1.2, XA1.D40
/D41: J1.4, XA1.D41
/D42: J1.6, XA1.D42
/D43: J1.8, XA1.D43
/D44: J1.10, XA1.D44
/D45: J1.12, XA1.D45
/D46: J1.14, XA1.D46
/D47: J1.16, XA1.D47
/D48: J1.18, XA1.D48
/D49: J1.20, XA1.D49
/GND: J1.19, J2.3, J3.2, SW1.1, XA1.GND1 (GND), XA1.GND2 (GND), XA1.GND3 (GND), XA1.GND4 (SPI_GND), XA1.GND5 (GND), XA1.GND6 (GND)
/IORF: XA1.IORF (IOREF)
/RST: SW1.2, XA1.RST1 (RESET)
/VIN: SW2.4

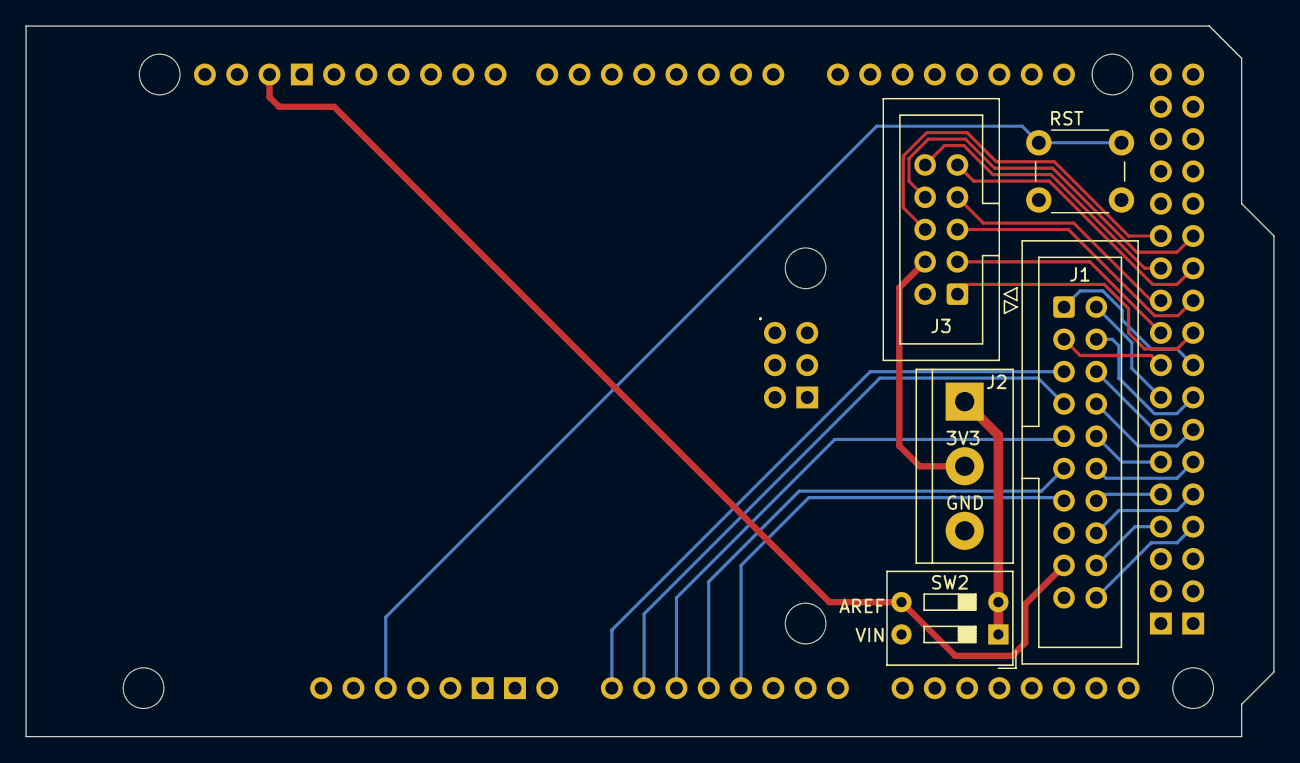
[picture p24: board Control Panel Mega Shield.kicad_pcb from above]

Board: 2 copper layers, 98.1 x 55.9 mm, 6 parts (0 on the bottom side), 30 nets.

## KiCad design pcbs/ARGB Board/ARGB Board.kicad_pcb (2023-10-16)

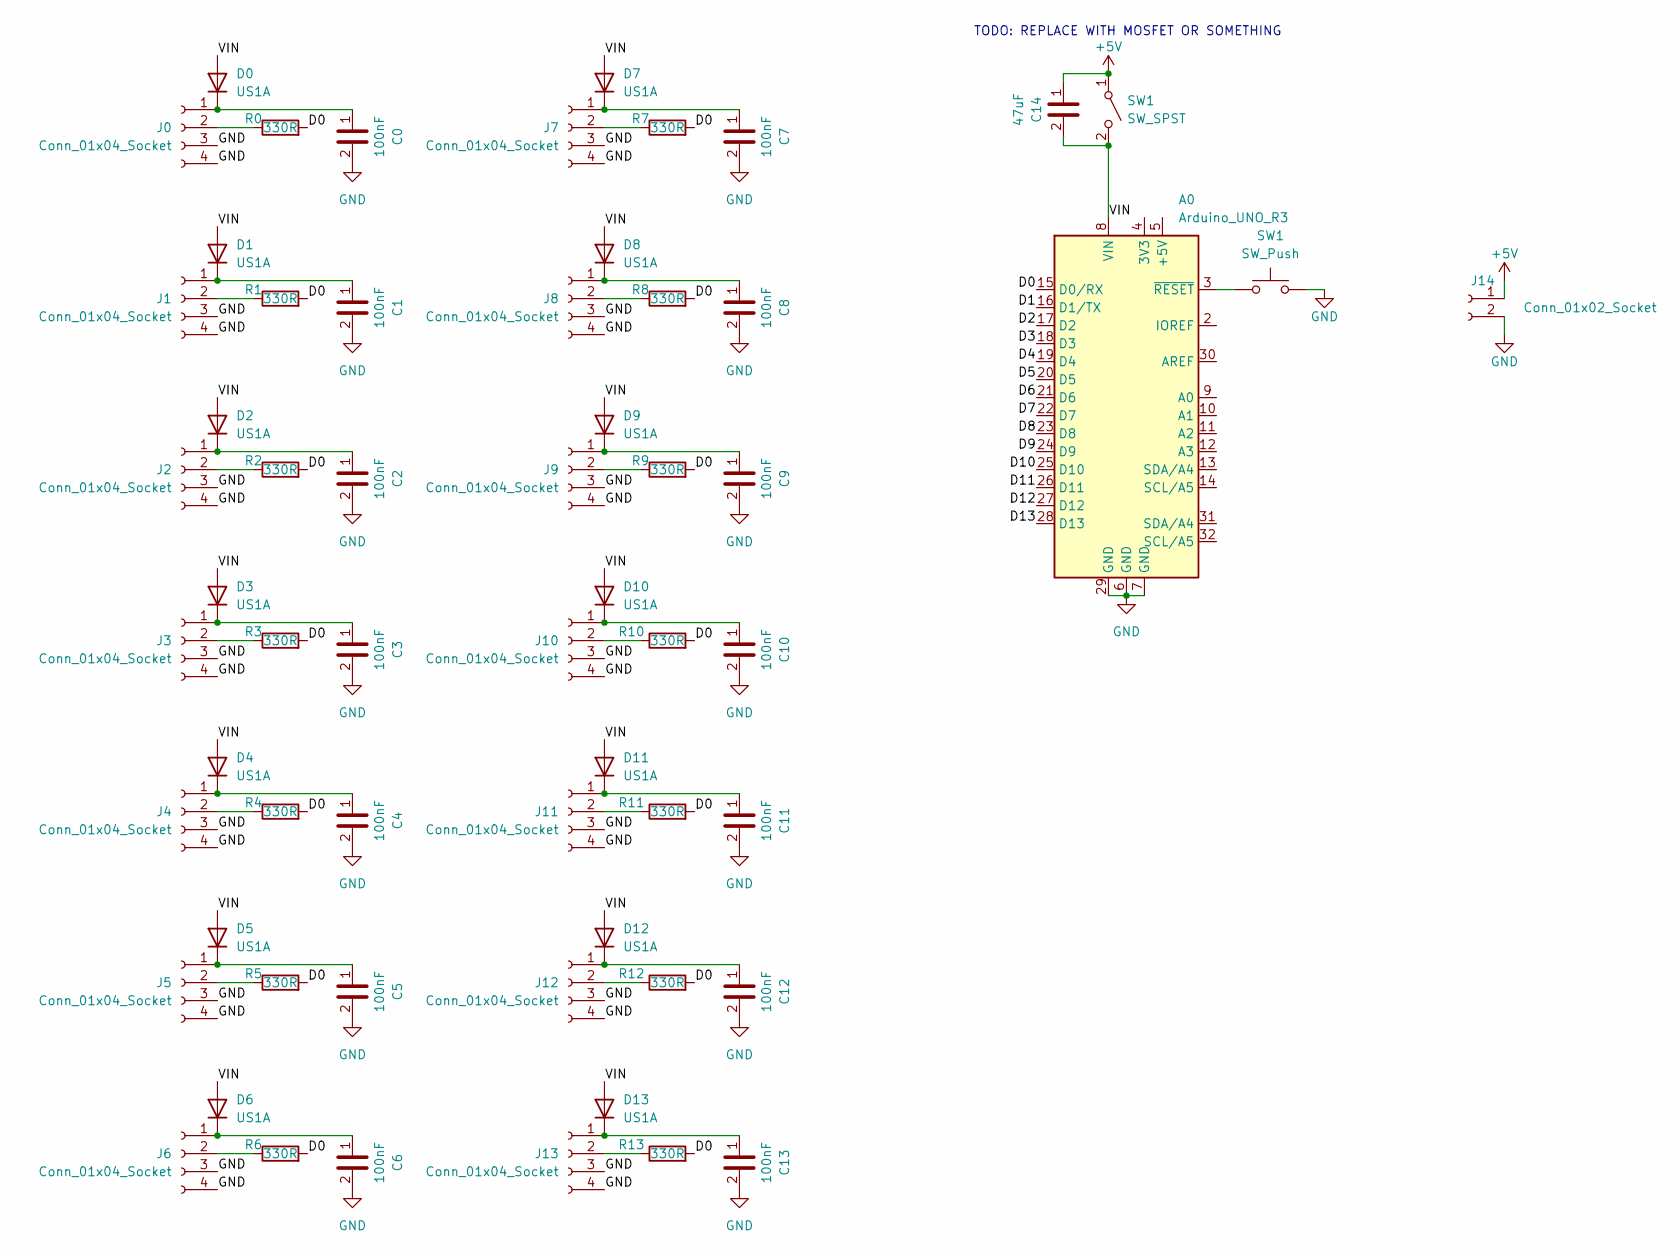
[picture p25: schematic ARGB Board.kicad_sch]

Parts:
A0: Arduino_UNO_R3; Arduino_UNO_R3_EdgeCuts
C0, C1, C2, C3, C4, C5, C6, C7, C8, C9, C10, C11, C12, C13: 100nF; C_0805_2012Metric_Pad1.18x1.45mm_HandSolder
C14: 47uF; CP_Radial_D6.3mm_P2.50mm
D0, D1, D2, D3, D4, D5, D6, D7, D8, D9, D10, D11, D12, D13: US1A; D_SMA
J0, J1, J2, J3, J4, J5, J6, J7, J8, J9, J10, J11, J12, J13: Conn_01x04_Socket; PinHeader_1x04_P2.54mm_Vertical
J14: Conn_01x02_Socket; TerminalBlock_bornier-2_P5.08mm
R0, R1, R2, R3, R4, R5, R6, R7, R8, R9, R10, R11, R12, R13: 330R; R_0805_2012Metric
SW1: SW_SPST; SW_E-Switch_EG1271_SPDT

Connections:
/D0: A0.15 (D0/RX), R0.2, R1.2, R2.2, R3.2, R4.2, R5.2, R6.2, R7.2, R8.2, R9.2, R10.2, R11.2, R12.2, R13.2
/D1: A0.16 (D1/TX)
/D2: A0.17 (D2)
/D3: A0.18 (D3)
/D4: A0.19 (D4)
/D5: A0.20 (D5)
/D6: A0.21 (D6)
/D7: A0.22 (D7)
/D8: A0.23 (D8)
/D9: A0.24 (D9)
/D10: A0.25 (D10)
/D11: A0.26 (D11)
/D12: A0.27 (D12)
/D13: A0.28 (D13)
unnamed: C0.1, D0.1 (K), J0.1
unnamed: C1.1, D1.1 (K), J1.1
unnamed: C2.1, D2.1 (K), J2.1
unnamed: C3.1, D3.1 (K), J3.1
unnamed: C4.1, D4.1 (K), J4.1
unnamed: C5.1, D5.1 (K), J5.1
unnamed: C6.1, D6.1 (K), J6.1
unnamed: C7.1, D7.1 (K), J7.1
unnamed: C8.1, D8.1 (K), J8.1
unnamed: C9.1, D9.1 (K), J9.1
unnamed: C10.1, D10.1 (K), J10.1
unnamed: C11.1, D11.1 (K), J11.1
unnamed: C12.1, D12.1 (K), J12.1
unnamed: C13.1, D13.1 (K), J13.1
unnamed: J0.2, R0.1
unnamed: J1.2, R1.1
unnamed: J2.2, R2.1
unnamed: J3.2, R3.1
unnamed: J4.2, R4.1
unnamed: J5.2, R5.1
unnamed: J6.2, R6.1
unnamed: J7.2, R7.1
unnamed: J8.2, R8.1
unnamed: J9.2, R9.1
unnamed: J10.2, R10.1
unnamed: J11.2, R11.1
unnamed: J12.2, R12.1
unnamed: J13.2, R13.1

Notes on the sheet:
TODO: REPLACE WITH MOSFET OR SOMETHING

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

Board: 2 copper layers, 75.2 x 53.6 mm, 61 parts (1 on the bottom side), 33 nets.

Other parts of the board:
SW0: SW_Push; SW_PUSH_6mm_H5mm

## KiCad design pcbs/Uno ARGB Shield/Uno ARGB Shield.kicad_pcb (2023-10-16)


Board: 2 copper layers, 68.6 x 53.3 mm, 8 parts (0 on the bottom side), 3 nets, no tracks yet.

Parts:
J1: Power; PinSocket_1x08_P2.54mm_Vertical
J2: Digital/PWM; PinSocket_1x10_P2.54mm_Vertical
J3: Analog; PinSocket_1x06_P2.54mm_Vertical
J4: Digital/PWM; PinSocket_1x08_P2.54mm_Vertical
MH1, MH2, MH3, MH4: MountingHole_3.2mm

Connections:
/SCL/A5: J2.1, J3.6
/SDA/A4: J2.2, J3.5
GND: J1.6, J1.7, J2.4

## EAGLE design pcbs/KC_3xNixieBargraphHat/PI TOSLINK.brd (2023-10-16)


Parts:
C1, C2: 10pF; 0805
C3, C5, C6, C7, C8, C9: 0.1µF; 0805
C4: 10µF; 0805
IC1: WM8804; SSOP20BU
L1: 400Ω; 0805
L2: 47µH; 0805
Q1: 27 MHz; NX3225
R1, R2, R3, R4: 10kΩ; 0805
U$2: PLR135/T10
U$3: PLT133/T8; PLR135/T10
X1: RASPI_GPIO_B+#_PIN; RASPI_GPIO_B+_PIN

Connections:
5V0A: X1.2 (5V0A)
5V0B: X1.4 (5V0B)
!RST: C8.2, IC1.6 (RESETB), R4.1
+3V3: C7.2, C9.1, IC1.19 (DVDD), L1.1, L2.1, R1.2, R3.1, R4.2, U$3.P$2 (VCC), X1.1 (3V3A), X1.17 (3V3B)
BCK: IC1.14 (BCLK), X1.12 (GPIO18)
DIN: IC1.12 (DOUT), X1.38 (GPIO20)
DOUT: IC1.13 (DIN), X1.40 (GPIO21)
GND: C1.1, C2.1, C3.1, C4.1, C6.1, C7.1, C8.1, C9.2, IC1.8 (PGND), IC1.18 (DGND), Q1.2 (G2), Q1.4 (G1), R2.1, U$2.P$2 (GND), U$3.P$3 (GND), X1.6 (GND_A), X1.9 (GND_B), X1.14 (GND_C), X1.20 (GND_D), X1.25 (GND_E), X1.30 (GND_F), X1.34 (GND_G), X1.39 (GND_H)
LRCK: IC1.15 (LRCK), X1.35 (GPIO19)
unnamed: C2.2, IC1.10 (XOP), Q1.3 (X2)
unnamed: C1.2, IC1.11 (XIN), Q1.1 (X1)
unnamed: C5.1, U$2.P$3 (OUT)
unnamed: IC1.2 (GP0/SWIFM), R2.2
unnamed: IC1.5 (CSB/GP1), R3.2
unnamed: C3.2, C4.2, IC1.7 (PVDD), L1.2
unnamed: C6.2, L2.2, U$2.P$1 (VCC)
SCL: IC1.1 (SCLK), X1.5 (SCL)
SDA: IC1.3 (SDIN/HWM), R1.1, X1.3 (SDA)
TOSRX: C5.2, IC1.20 (RX0)
TOSTX: IC1.17 (TX0), U$3.P$1 (IN)


Board: 2 copper layers, 22.9 x 53.3 mm, 20 parts (0 on the bottom side), 18 nets.

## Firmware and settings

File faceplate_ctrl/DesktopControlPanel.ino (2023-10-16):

#include "DesktopControlPanel.h"
#define DECODE_NEC
#define DEBUG
#define RAW_BUFFER_LENGTH 132
// #include <IRremote.hpp>

// ARGB
CHSV argbHSV;

// Faceplate
bool pcAudioMode = false;
bool pcAudioModePrev = false;
bool ctrlMode;
bool lightTemperatureMode = false;
// Motors
// Init one motor on the Adafruit Motor Shield v2.3
Adafruit_MotorShield AFMS = Adafruit_MotorShield();
Adafruit_DCMotor *motor1 = AFMS.getMotor(1);
Adafruit_DCMotor *motor2 = AFMS.getMotor(2);
Adafruit_DCMotor *motor3 = AFMS.getMotor(3);

Potentiometer pot1 = Potentiometer(POT1_PIN, ANALOG_MAX, POT_ANGLE_MIN, POT_ANGLE_MAX, POT_LINEAR, motor1);
Potentiometer pot2 = Potentiometer(POT2_PIN, ANALOG_MAX, POT_ANGLE_MIN, POT_ANGLE_MAX, POT_LINEAR, motor2);
Potentiometer pot3 = Potentiometer(POT3_PIN, ANALOG_MAX, POT_ANGLE_MIN, POT_ANGLE_MAX, POT_LINEAR, motor3);
Potentiometer pot4 = Potentiometer(POT4_PIN, ANALOG_MAX, POT_ANGLE_MIN, POT_ANGLE_MAX, POT_LOGARITHMIC);

SoftTakeoverLEDs pot1LEDs = SoftTakeoverLEDs(2, POT_ANGLE_MIN, POT_ANGLE_MAX, STO1_LED1_PIN, STO1_LED2_PIN);
SoftTakeoverLEDs pot2LEDs = SoftTakeoverLEDs(2, POT_ANGLE_MIN, POT_ANGLE_MAX, STO2_LED1_PIN, STO2_LED2_PIN);
SoftTakeoverLEDs pot3LEDs = SoftTakeoverLEDs(2, POT_ANGLE_MIN, POT_ANGLE_MAX, STO3_LED1_PIN, STO3_LED2_PIN);

ControlPot ctrlPotKelv = ControlPot(&pot1, ARGB_LED_KELV_MIN, ARGB_LED_KELV_MAX, &pot1LEDs);
ControlPot ctrlPotHue  = ControlPot(&pot1, ARGB_LED_HUE_MIN, ARGB_LED_HUE_MAX, &pot1LEDs);
ControlPot ctrlPotSat  = ControlPot(&pot2, ARGB_LED_SAT_MIN, ARGB_LED_SAT_MAX, &pot2LEDs);
ControlPot ctrlPotVal  = ControlPot(&pot3, ARGB_LED_VAL_MIN, ARGB_LED_VAL_MAX, &pot3LEDs);
ControlPot ctrlPotPCVolApp1 = ControlPot(&pot1, 0, ANALOG_MAX, &pot1LEDs);
ControlPot ctrlPotPCVolApp2 = ControlPot(&pot2, 0, ANALOG_MAX, &pot2LEDs);
ControlPot ctrlPotPCVolApp3 = ControlPot(&pot3, 0, ANALOG_MAX, &pot3LEDs);
ControlPot ctrlPotPCVolMain = ControlPot(&pot4, 0, ANALOG_MAX);

uint16_t pcVolumeApp1;
uint16_t pcVolumeApp2;
uint16_t pcVolumeApp3;
uint16_t pcVolumeMain;

ToggleSwitch tglAudio =     ToggleSwitch(SW_T_1_PIN, OPTO_1_ON_PIN, OPTO_1_OFF_PIN);
// Opto pair 3 controls only one outlet only due to wiring issues: this is the behaviour I want for toggle 2
ToggleSwitch tglMonitorMain =  ToggleSwitch(SW_T_2_PIN, OPTO_3_ON_PIN, OPTO_3_OFF_PIN);
// Opto pair 2 controls only two outlets due to wiring issues: this is the behaviour I want for toggle 3
ToggleSwitch tglMonitorBoth =  ToggleSwitch(SW_T_3_PIN, OPTO_2_ON_PIN, OPTO_2_OFF_PIN);

//Serial
uint32_t serialWriteTimeLast = 0;

void setup() {
    setupSerial();
    setupPinModes();    
    setupMotors();
    setupInitialValues();
}

void loop() {
    readFaceplateInputs();    
    setActiveControlPots();
    moveAllMotors();
    getControlPotValues();
    setARGBColorValues();
    setVolumeValues();
    // setARGBStripColorValues();
    sendCommandsToPCIfWriteTimeElapsed();
    // printDiagnostics();
}

void setupSerial() {
    Serial.begin(9600);
    // Serial.println(F("START " __FILE__ " at " __TIMESTAMP__));
    Serial.flush();
}

void setupPinModes() {
    pinMode(SW_R_1_PIN, INPUT_PULLUP);
    pinMode(SW_R_2_PIN, INPUT_PULLUP);
    pinMode(SW_R_3_PIN, INPUT_PULLUP);
    pinMode(SW_R_4_PIN, INPUT_PULLUP);
    pinMode(SW_P_1_PIN, INPUT_PULLUP);
    pinMode(SW_P_2_PIN, INPUT_PULLUP);
    pinMode(SW_P_3_PIN, INPUT_PULLUP);
    pinMode(ARGBW_G_PIN, OUTPUT);
}

void setupMotors() {
    AFMS.begin();
    motor1->setSpeed(0);
    motor1->run(RELEASE);
    motor2->setSpeed(0);
    motor2->run(RELEASE);
    motor3->setSpeed(0);
    motor3->run(RELEASE);
}

void setupInitialValues() {
    pcAudioMode = digitalRead(SW_R_4_PIN);
    ctrlMode = digitalRead(SW_R_3_PIN);
    lightTemperatureMode = digitalRead(SW_T_2_PIN);
    initAllControlPotValues();
    setARGBColorValues();
    setVolumeValues();
}

void initAllControlPotValues() {
    ctrlPotKelv.setValue();
    ctrlPotHue.setValue();
    ctrlPotSat.setValue();
    ctrlPotVal.setValue();
    ctrlPotPCVolApp1.setValue();
    ctrlPotPCVolApp2.setValue();
    ctrlPotPCVolApp3.setValue();
    ctrlPotPCVolMain.setValue();
}

void setARGBColorValues() {
    if (lightTemperatureMode) {
        argbHSV = colorTemperatureToHSV(ctrlPotKelv.getValue());
    }
    else {
        argbHSV = colorHueToHSV(ctrlPotHue.getValue());
    }
    argbHSV.sat *= ctrlPotSat.getValuePercent();
    argbHSV.val *= ctrlPotVal.getValuePercent();
}

void setVolumeValues() {
    pcVolumeApp1 = ctrlPotPCVolApp1.getValue();
    pcVolumeApp2 = ctrlPotPCVolApp2.getValue();
    pcVolumeApp3 = ctrlPotPCVolApp3.getValue();
    pcVolumeMain = ctrlPotPCVolMain.getValue();
}

void readFaceplateInputs() {
    pcAudioModePrev = pcAudioMode;
    pcAudioMode = digitalRead(SW_R_4_PIN);
    ctrlMode = digitalRead(SW_R_3_PIN);
    lightTemperatureMode = digitalRead(SW_R_2_PIN);
    tglAudio.set();
    tglMonitorMain.set();
    tglMonitorBoth.set();
    pcVolumeMain = ctrlPotPCVolMain.getValue(); // Always read: app-specific volumes are only read when needed
}

void setActiveControlPots() {
    if (ctrlMode == CTRL_MODE_ARGB) {
        ctrlPotKelv.setActive(lightTemperatureMode);
        ctrlPotHue.setActive(!lightTemperatureMode);
        ctrlPotSat.setActive(true);
        ctrlPotVal.setActive(true);
        ctrlPotPCVolApp1.setActive(false);
        ctrlPotPCVolApp2.setActive(false);
        ctrlPotPCVolApp3.setActive(false);
    }
    else if (ctrlMode == CTRL_MODE_VOLUME) {
        ctrlPotKelv.setActive(false);
        ctrlPotHue.setActive(false);
        ctrlPotSat.setActive(false);
        ctrlPotVal.setActive(false);
        ctrlPotPCVolApp1.setActive(true);
        ctrlPotPCVolApp2.setActive(true);
        ctrlPotPCVolApp3.setActive(true);
    }    
    ctrlPotPCVolMain.setActive(true);
}

void moveAllMotors() {
    pot1.moveMotor();
    pot2.moveMotor();
    pot3.moveMotor();
}

void getControlPotValues() {
    ctrlPotKelv.getValue();
    ctrlPotHue.getValue();
    ctrlPotSat.getValue();
    ctrlPotVal.getValue();
    ctrlPotPCVolApp1.getValue();
    ctrlPotPCVolApp2.getValue();
    ctrlPotPCVolApp3.getValue();
    ctrlPotPCVolMain.getValue();
}

void setARGBStripColorValues() {
    int val = int(float(analogRead(POT1_PIN)) / 4.0);
    analogWrite(ARGBW_G_PIN, val);
}

void sendCommandsToPCIfWriteTimeElapsed() {
    if (commandWriteTimeHasElapsed()) {
        String commands;
        commands = getCommands();
        Serial.println(commands);
        Serial.flush();
    }
}

bool commandWriteTimeHasElapsed() {
    static uint32_t lastWriteTime;
    const uint8_t updatesPerSecond = 100;
    const uint16_t writePeriod = 1000/updatesPerSecond;
    if (periodHasElapsedSinceLastTime(writePeriod, lastWriteTime)) {
        lastWriteTime = millis();
        return true;
    }
    return false;
}

bool periodHasElapsedSinceLastTime(uint32_t period, uint32_t lastTime) {
    return ((millis() - lastTime) > period);
}

int16_t scaleValueByControlPot(int value, ControlPot *ctrlPot) {
    return value *= float(ctrlPot->getValue()) / float(ctrlPot->getValueMax());
}

String getCommands() {
    String commands = "_";
    commands += ",A " + String(pcAudioMode);
    commands += ",V1 " + String(pcVolumeApp1);
    commands += ",V2 " + String(pcVolumeApp2);
    commands += ",V3 " + String(pcVolumeApp3);
    commands += ",VM " + String(pcVolumeMain);
    commands += ",H " + String(argbHSV.hue);
    commands += ",S " + String(argbHSV.sat);
    commands += ",V " + String(argbHSV.val);
    return commands;
}

void printDiagnostics() {
    char text[150];
    int rsw1 = digitalRead(SW_R_1_PIN);
    int rsw2 = digitalRead(SW_R_2_PIN);
    int rsw3 = digitalRead(SW_R_3_PIN);
    int rsw4 = digitalRead(SW_R_4_PIN);
    int tsw1 = !digitalRead(SW_T_1_PIN);
    int tsw2 = !digitalRead(SW_T_2_PIN);
    int tsw3 = !digitalRead(SW_T_3_PIN);
    int psw1 = digitalRead(SW_P_1_PIN);
    int psw2 = digitalRead(SW_P_2_PIN);
    int psw3 = digitalRead(SW_P_3_PIN);
    int pot1 = analogRead(POT1_PIN);
    int pot2 = analogRead(POT2_PIN);
    int pot3 = analogRead(POT3_PIN);
    int pot4 = analogRead(POT4_PIN);
    
    sprintf(text, "rsw1 %04i rsw2 %04i rsw3 %04i rsw4 %04i || tsw1 %04i tsw2 %04i tsw3  %04i || psw1 %04i psw2 %04i psw3 %04i || pot1 %04i pot2 %04i pot3 %04i pot4 %04i",
    rsw1, rsw2, rsw3, rsw4, tsw1, tsw2, tsw3, psw1, psw2, psw3, pot1, pot2, pot3, pot4);
    // Serial.println(text);
    
    char hsv_values[12];
    uint16_t temp = ctrlPotKelv.getValue();
    sprintf(hsv_values, "%04i %03i %03i %03i", temp, argbHSV.h, argbHSV.s, argbHSV.v);
    char volume_values[24];
    sprintf(volume_values, "%04i %04i %04i %04i", ctrlPotPCVolApp1.getValue(), ctrlPotPCVolApp2.getValue(), ctrlPotPCVolApp3.getValue(), ctrlPotPCVolMain.getValue());
    Serial.print(hsv_values);
    Serial.print(" || ");
    Serial.println(volume_values);
}

void showSTOLeds() {
    const int ledNum = 6;
    int pins[ledNum] = {STO1_LED1_PIN, STO1_LED2_PIN, STO2_LED1_PIN, STO2_LED2_PIN, STO3_LED1_PIN, STO3_LED2_PIN};
    static int pin = 0;
    for (int i = 0; i < ledNum; i++) {
        analogWrite(pins[i], (i = pin) ? 255 : 0);
    }
    pin = (pin < ledNum) ? pin + 1 : 0;
}

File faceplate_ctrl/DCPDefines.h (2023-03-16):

#ifndef DCP_DEFINES_H
#define DCP_DEFINES_H

// System parameters
#define ANALOG_MAX 1023
#define UPDATE true

// Serial
#define SERIAL_WRITE_PERIOD 10

// ARGB
#define ARGB_LED_HUE_MIN 0
#define ARGB_LED_HUE_MAX 255
#define ARGB_LED_KELV_MIN 1500 // "kelv" used for temperature to avoid confusion at "temp" values
#define ARGB_LED_KELV_MAX 6500
#define ARGB_LED_SAT_MIN 0
#define ARGB_LED_SAT_MAX 255
#define ARGB_LED_VAL_MIN 0
#define ARGB_LED_VAL_MAX 170

#define ARGBW_G_PIN 10

// Potentiometers
#define POT1_PIN A1
#define POT2_PIN A2
#define POT3_PIN A3
#define POT4_PIN A0
#define POT_DIFF_MIN 2
#define POT_LINEAR false
#define POT_LOGARITHMIC true
#define POT_ANGLE_MIN 240
#define POT_ANGLE_MAX -60
#define POT_STO_LED_NUM 2

// Rocker Switches
#define SW_R_1_PIN 22
#define SW_R_2_PIN 23
#define SW_R_3_PIN 24
#define SW_R_4_PIN 25

// Toggle Switches
#define SW_T_1_PIN 26
#define SW_T_2_PIN 27
#define SW_T_3_PIN 28
// Toggle switches 4 and 5 are hard-wired

// Push Switches
#define SW_P_1_PIN 31
#define SW_P_2_PIN 32
#define SW_P_3_PIN 33

// Optocouplers
#define OPTO_1_ON_PIN   42
#define OPTO_1_OFF_PIN  44
#define OPTO_2_ON_PIN   46
#define OPTO_2_OFF_PIN  48
#define OPTO_3_ON_PIN   50
#define OPTO_3_OFF_PIN  52
#define OPTO_PULSE_LENGTH 1000

// Control mode
#define CTRL_MODE_VOLUME 1
#define CTRL_MODE_ARGB 0

// Audio Control
#define VOLUME_MAX ANALOG_MAX
#define VOLUME_MIN_DIFF 2
#define AUDIO_SOUNDCARD 0
#define AUDIO_HEADPHONES 1

// ControlPot parameters
#define STO_DISABLE_THRESHOLD 5
#define STO1_LED1_PIN 6 //6
#define STO1_LED2_PIN 4 //
#define STO2_LED1_PIN 5 //
#define STO2_LED2_PIN 8
#define STO3_LED1_PIN 7 //
#define STO3_LED2_PIN 3 // 2
#define STO_LEDS_MAX 2
#define STO_LED_MAX_BRIGHTNESS 255
#define STO_LED_MIN_BRIGHTNESS 10
#define CURRENT 0
#define PREVIOUS 1

// IR Transmitter
#define IR_RX_PIN 50
#define IR_TX_PIN 9
#define IR_AIRCON_ON 
#define IR_AIRCON_OFF 

// RF Remote
#define RF_A_ON_PIN 48
#define RF_A_OFF_PIN 50

#endif

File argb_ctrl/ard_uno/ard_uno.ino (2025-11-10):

#include "ard_uno.h"

// ARGB
CHSV argbHSV;
CRGB fanTopRearPixels[ARGB_FAN_TOP_REAR_LED_NUM];
CRGB fanTopFrontPixels[ARGB_FAN_TOP_FRONT_LED_NUM];
CRGB fanFrontTopPixels[ARGB_FAN_FRONT_TOP_LED_NUM];
CRGB fanFrontMidPixels[ARGB_FAN_FRONT_MID_LED_NUM];
CRGB fanFrontLowPixels[ARGB_FAN_FRONT_LOW_LED_NUM];
CRGB fanRearPixels[ARGB_FAN_REAR_LED_NUM];
CRGB supportPixels[ARGB_SUPPORT_LED_NUM];

//Serial
uint32_t serialWriteTimeLast = 0;

void setup() {
    setupSerial();
    setupLighting();
}

void loop() {
    getColorValuesFromSerial();
    showARGBColorIfDisplayTimeElapsed();
}

void setupSerial() {
    Serial.begin(9600);
    Serial.flush();
}

void setupLighting() {
    FastLED.addLeds<ARGB_FAN_TOP_REAR_CHIPSET,ARGB_FAN_TOP_REAR_PIN,ARGB_FAN_TOP_REAR_ORDER>(fanTopRearPixels,ARGB_FAN_TOP_REAR_LED_NUM);
    FastLED.addLeds<ARGB_FAN_TOP_FRONT_CHIPSET,ARGB_FAN_TOP_FRONT_PIN,ARGB_FAN_TOP_FRONT_ORDER>(fanTopFrontPixels,ARGB_FAN_TOP_FRONT_LED_NUM);
    FastLED.addLeds<ARGB_FAN_FRONT_TOP_CHIPSET,ARGB_FAN_FRONT_TOP_PIN,ARGB_FAN_FRONT_TOP_ORDER>(fanFrontTopPixels,ARGB_FAN_FRONT_TOP_LED_NUM);
    FastLED.addLeds<ARGB_FAN_FRONT_MID_CHIPSET,ARGB_FAN_FRONT_MID_PIN,ARGB_FAN_FRONT_MID_ORDER>(fanFrontMidPixels,ARGB_FAN_FRONT_MID_LED_NUM);
    FastLED.addLeds<ARGB_FAN_FRONT_LOW_CHIPSET,ARGB_FAN_FRONT_LOW_PIN,ARGB_FAN_FRONT_LOW_ORDER>(fanFrontLowPixels,ARGB_FAN_FRONT_LOW_LED_NUM);
    FastLED.addLeds<ARGB_FAN_REAR_CHIPSET,ARGB_FAN_REAR_PIN,ARGB_FAN_REAR_ORDER>(fanRearPixels,ARGB_FAN_REAR_LED_NUM);
    FastLED.addLeds<ARGB_SUPPORT_CHIPSET,ARGB_SUPPORT_PIN,ARGB_SUPPORT_ORDER>(supportPixels,ARGB_SUPPORT_LED_NUM);
    delay(1000);
    FastLED.clear(true);
    delay(1000);
    // Set to half-brightness white to indicate "Started, no serial received".
    argbHSV = CHSV(0, ARGB_LED_SAT_MIN, ARGB_LED_VAL_MAX / 2);
    FastLED.showColor(argbHSV, ARGB_LED_VAL_MAX);
    delay(1000);
}

void getColorValuesFromSerial() {
    if (Serial.available() >= 4 && Serial.read() == '_') {
        uint8_t colorValues[3];
        for (int i = 0; i < 3; i++) {
            colorValues[i] = uint8_t(Serial.read());
        }
        argbHSV = CHSV(colorValues[0], colorValues[1], colorValues[2]);
        Serial.flush();
    }
}

void showARGBColorIfDisplayTimeElapsed() {
    if (ARGBDisplayTimeHasElapsed()) {
        FastLED.showColor(argbHSV, ARGB_LED_VAL_MAX);
    }
}

bool ARGBDisplayTimeHasElapsed() {
    static uint32_t argbDisplayTimeLast;
    const uint16_t argbDisplayPeriod = 1000/ARGB_LED_FPS;
    if (periodHasElapsedSinceLastTime(argbDisplayTimeLast, argbDisplayPeriod)) {
        argbDisplayTimeLast = millis();
        return true;
    }
    return false;
}

bool periodHasElapsedSinceLastTime(uint32_t period, uint32_t lastTime) {
    return ((millis() - lastTime) > period);
}

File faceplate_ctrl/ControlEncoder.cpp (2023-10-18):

#include "ControlEncoder.h"

ControlEncoder::ControlEncoder(uint8_t clk, uint8_t dt, uint8_t sw)
    : clkPin(clk), dtPin(dt), swPin(sw)
    {
        pinMode(clkPin, INPUT);
        pinMode(dtPin, INPUT);
        pinMode(swPin, INPUT);
        clkPinStateLast = digitalRead(clkPin);
        swButtonStateLast = digitalRead(swPin);
        swPinDebounceTimeLast = 0;
        value = 0;
    }

uint16_t ControlEncoder::getValue() {
    return value;
}

void ControlEncoder::updateValue() {
    bool clkPinState = digitalRead(clkPin);
    bool dtPinState = digitalRead(dtPin);
    readButtonDebounced(&swButtonState, &swPin, &swPinReadLast, &swPinDebounceTimeLast);    
    if (swButtonState = LOW) {
        value = 0;
    }
    else if (clkPinState != clkPinStateLast) {
        if (dtPinState != clkPinState) {
            value++; // Encoder rotating clockwise
        }
        else {
            value--; // Encoder rotating counter-clockwise
        }
    }
    clkPinStateLast = clkPinState;
    swButtonStateLast = swButtonState;
}

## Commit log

2023-02-16 Uploaded working files from Raspberry Pi. Webpage is ready for hosting.
2023-02-16 Added app.py and templates folder to staged changes.
2023-03-17 Added motorised takeover
2023-10-16 Bulk pre-portfolio commit
    [#002_mounting_plate.dxf, #002_mounting_plate_micromotor.dxf, 000_all_pieces.dxf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]
2023-10-16 Added missing /audio files
    The original three files appear to be test recordings: the rest were stored in the DCP repo, I believe to save space on my Raspberry Pi, which I now see is unnecessary.
2023-10-16 Merged py folders for PC and raspi
    Raspi scripts for arduino/pc comms and PC scripts for raspi comms/volume control have been merged into one py directory.
2023-10-16 Added ESPWifiARGBControl code from offline repo
    This logic was developed offline by mistake briefly, and is now being merged into the main repo
    [ESPWifiARGBController.ino]
2023-10-16 Added RF test code from offline repo
    This logic was tested offline by mistake briefly, and is now being merged into the online repo
    [RF_Test.ino]
2023-10-16 Added pcbs directory
    Added new directory for the PCB dev files (mostly kicad files)
    [ARGB Board.kicad_pcb, ARGB Board.kicad_sch, AnalogFilterTest.kicad_pcb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]
2023-10-16 Create cabinet dir as root for hardware files
    Created cabinet dir and moved faceplate inside. Added folders for existing dwg and f3d files
    [001_face_plate.dxf, 001_face_plate.f3d, 002_mounting_plate.dxf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]
2023-10-18 Updates to dir names, added .gitignore
    Moved "js_test" to "eink" dir after review of contents. Added .gitignore, added KiCad backup dirs to ignore list.
2023-10-18 Reorganised folders based on hardware components
    [#002_mounting_plate.dxf, #002_mounting_plate_micromotor.dxf, 000_all_pieces.dxf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]

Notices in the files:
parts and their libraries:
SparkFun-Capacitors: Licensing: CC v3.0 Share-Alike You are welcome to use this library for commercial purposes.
